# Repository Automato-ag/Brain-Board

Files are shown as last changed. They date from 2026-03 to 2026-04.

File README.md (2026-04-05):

# Brain Board — Automato Ag

Firmware and documentation for the **Automato Brain Board V2.0**, an ESP32-C6 based agricultural IoT node with onboard temperature, humidity, and light sensing, ESP-NOW mesh networking, relay control, and a self-hosted web dashboard served directly from the board.

---

## Hardware

| Component | Details |
|---|---|
| MCU | ESP32-C6-MINI-1-N4, 160 MHz, 4 MB Flash |
| Temp/Humidity | SHTC3 — I2C 0x70 (fixed) |
| Light | TSL2591 — I2C 0x29 (fixed) |
| I2C Bus | SDA = IO6, SCL = IO7 |
| Blue LED | IO23 |
| Red LED | IO22 |
| Boot Button | IO9 — see Boot Button section below |
| Qwiic/STEMMA QT | J2, J3 — GND / 3V3 / SDA / SCL |
| Logic Level | 3.3V only — GPIO pins not 5V tolerant |

See [`hardware/Brain_Board_Reference.md`](hardware/Brain_Board_Reference.md) for full pinout and hardware notes.

---

## Firmware

### Current Version

| Sketch | Version |
|---|---|
| [`BrainBoard_v110`](firmware/BrainBoard/BrainBoard_v110/) | **v1.1.0** |

All boards run the same unified firmware. There is no separate Host or Remote build — role (gateway, relay, isolated) is determined automatically at runtime based on WiFi connectivity.

### Required Libraries

Install all of the following via **Arduino Library Manager**:

- `Adafruit SHTC3 Library`
- `Adafruit TSL2591`
- `Adafruit BusIO` *(installed automatically as dependency)*
- `Adafruit Unified Sensor` *(installed automatically as dependency)*
- `SparkFun TCA9534` *(for Qwiic GPIO relay control)*

### Arduino IDE Settings

| Setting | Value |
|---|---|
| Board | ESP32C6 Dev Module |
| USB CDC On Boot | **Enabled** — required; board crashes on Serial without this |
| Partition Scheme | **Custom** — required; uses `partitions.csv` in sketch folder |
| Upload Speed | 921600 |

> **Note:** USB CDC on Boot must be re-enabled each Arduino IDE session — it does not always persist.

### First Flash

1. Open `BrainBoard_v110/BrainBoard_v110.ino` in Arduino IDE
2. Set board settings as above
3. **Sketch → Upload** — flash firmware
4. **Tools → ESP32 Sketch Data Upload** — upload `data/` folder to LittleFS
5. Open Serial Monitor at 115200 baud, press RESET
6. Connect phone or laptop to the `Automato-XXXX` WiFi network
7. Open `http://192.168.4.1/setup` — enter your Network Name, password, and WiFi credentials
8. Board joins your network and is accessible at `http://networkname.local`

### OTA Updates (after first flash)

- Navigate to `http://boardname.local/update` or `http://192.168.4.1/update`
- Upload new firmware `.bin` or new LittleFS filesystem image
- Firmware and webapp update independently — UI changes do not require reflashing firmware

### Boot Button (IO9)

| Action | Behavior |
|---|---|
| Hold 5s at **startup** | Clears all stored credentials and settings, then reboots |
| Short press during **runtime** | Opens a 10-minute SoftAP access window — board stays accessible at `192.168.4.1` even when on WiFi (useful for field configuration) |

---

## Dashboard

The Brain Board serves a complete webapp directly from its own flash memory — no internet, cloud, or external server required. Works in a field with no cell service.

### Tabs

| Tab | Description | Status |
|---|---|---|
| Dashboard | Live sensor readings, relay control, Agri Data sidebar | Live |
| Devices | Local + peer I2C scan, user-defined device labels, address reference | Live |
| Rules | Automation rule engine — local and cross-board conditions | v1.2 |
| Settings | Display & Behavior (units, refresh rate, auto-sync), Agri Data Sources, Board Settings | Live |
| Network | Mesh topology — board roles, peers, gateway address | Live |

### HTTP Endpoints

| Endpoint | Method | Description |
|---|---|---|
| `/` | GET | Dashboard webapp (served from LittleFS) |
| `/data` | GET | Sensor JSON + relay state + network info |
| `/peers` | GET | Peer list JSON |
| `/version` | GET | Firmware + webapp version, mDNS name, network name |
| `/relay` | GET | Relay control (`?state=0\|1`, `?override=auto`) |
| `/relay/status` | GET | Relay state JSON |
| `/i2c-scan` | GET | Local I2C bus scan |
| `/remote-scan` | POST/GET | Peer I2C scan via ESP-NOW |
| `/time` | POST | Set board time from browser |
| `/settings` | POST | Save board name / Network Name / password |
| `/proxy` | GET | HTTPS relay — board fetches external API on browser's behalf (`?url=`); allowlisted domains only |
| `/prefs` | GET | Read dashboard preferences from LittleFS (`/prefs.json`) |
| `/prefs` | POST | Write dashboard preferences JSON to LittleFS |
| `/setup` | GET/POST | WiFi provisioning form |
| `/wifi/reset` | POST | Clear WiFi credentials + reboot |
| `/update` | GET | OTA update UI |
| `/update/firmware` | POST | Flash new firmware `.bin` |
| `/update/filesystem` | POST | Flash new LittleFS image |

### Agri Data Sidebar

External API calls are routed through the board's `/proxy` endpoint so they work when connected to the board's SoftAP (phone in the field with no direct internet). All sources are free and require no API keys.

Data sources can be enabled or disabled individually from **Settings → Agri Data Sources**.

| Parameter Group | Source |
|---|---|
| Weather, Wind, Cloud Cover, Outdoor Humidity | Open-Meteo |
| Solar, UV Index, Shortwave Radiation | Open-Meteo |
| First Light, Sunrise, Solar Noon, Sunset, Day Length | Sunrise-Sunset.org |
| Soil Temperature and Moisture, ET₀, VPD | Open-Meteo |
| Frost Risk (derived) | Open-Meteo (radiative cooling model) |
| Growing Degree Days — season to date (derived) | Open-Meteo + ERA5 archive |
| Chill Hours — season to date (derived) | Open-Meteo + ERA5 archive |
| Photoperiod — day length classification (derived) | Sunrise-Sunset.org |
| Moon Phase, Moonrise, Moonset | USNO + Sunrise-Sunset.org |
| NWS Frost Alerts | NOAA National Weather Service |
| PM2.5, Pollen | Open-Meteo Air Quality |
| DLI Accumulator (onboard sensor) | TSL2591 lux — accumulated in firmware |

---

## ESP-NOW Mesh

All Brain Boards on the same Network Name automatically form a mesh using ESP-NOW. No configuration required beyond giving boards the same Network Name in `/setup`.

| Role | Condition | Behavior |
|---|---|---|
| Gateway | Board has active WiFi | Serves dashboard at `networkname.local`; syncs NTP time; relays peer sensor data |
| Relay | No WiFi, peer discovered | Seeks mesh channel, locks on discovery, forwards sensor data to gateway via ESP-NOW |
| Isolated | No WiFi, no peers found | Seeks continuously; accessible at `192.168.4.1` via its own SoftAP |

**Channel seek:** Non-WiFi boards cycle through channels 1–11 (US), restarting their SoftAP on each channel to keep the radio active for ESP-NOW reception. Lock occurs on first matching MSG_HELLO beacon.

**Plugin hooks:** Add a `custom.ino` file to the sketch folder to extend functionality without modifying core firmware. Available hooks: `customSetup()`, `customLoop()`, `customDataJSON()`.

---

## Relay Control

- GPIO expander: SparkFun Qwiic GPIO (TCA9534) at I2C address 0x27, connected via Qwiic cable
- Relay defaults **OFF** at all times — boot, sensor failure, I2C error, connectivity loss
- Manual ON/OFF toggle in dashboard always overrides automation
- Rule engine arriving in v1.2

## Relay Safety Contract

Relays default **OFF** under all failure conditions: boot, sensor failure, WiFi loss, cloud loss, browser closed, no rules configured, conflicting rules, hardware expander not found.

**There is no condition under which a relay defaults ON.**

---

## Roadmap

| Version | Feature | Status |
|---|---|---|
| v0.8.1 | Tab navigation shell, I2C Scanner tab, `/i2c-scan` endpoint | Complete |
| v0.9 | Devices tab, remote I2C scan via ESP-NOW, Network Name in `/setup` | Complete |
| v1.0 | Settings tab, Network tab stub, `POST /settings` endpoint | Complete |
| v1.1 | ESP-NOW mesh — unified firmware, MSG_HELLO beacon, dynamic gateway, `networkname.local`, 1-hop relay, live Network tab, plugin hooks | Complete |
| v1.2 | Rules tab — firmware rule engine, LittleFS persistence, local + peer conditions, recipe database | Next |
| v1.3 | Multi-hop relay, routing tables, cross-board rules | Planned |

---

## Repository Structure

```
Brain-Board/
├── README.md
├── CHANGELOG.md
├── LICENSE
├── .gitignore
├── firmware/
│   ├── BrainBoard/
│   │   └── BrainBoard_v110/            <- current (v1.1)
│   │       ├── BrainBoard_v110.ino
│   │       ├── partitions.csv
│   │       └── data/
│   │           ├── index.html
│   │           └── version.txt
│   ├── BrainBoard_Host/                <- legacy (pre-v1.1)
│   └── BrainBoard_Remote/              <- legacy (pre-v1.1, retired)
├── docs/
│   ├── Roadmap.md
│   ├── QuickStart.md
│   ├── RelayControl.md
│   ├── AgriDataSidebar.md
│   ├── ESP32C6_Capabilities.md
│   ├── I2C_Address_Map.md
│   └── ProductFamily.md
├── hardware/
│   ├── README.md
│   ├── Brain_Board_Reference.md
│   └── kicad/
│       └── Brain_Board_V2.0/
└── tools/
    └── I2C_Scanner/
        └── I2C_Scanner.ino
```

---

## License

MIT License — see [LICENSE](LICENSE) for details.

---

*Automato Ag — [automato.ag](https://automato.ag)*

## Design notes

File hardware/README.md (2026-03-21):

# Automato Brain Board V2.0 — Hardware Files

This folder contains hardware design files for the Automato Brain Board V2.0.

---

## Files

### Brain_Board_Reference.md
Complete hardware reference — MCU specs, pin definitions, I2C addresses, power rails, and peripheral wiring.

### kicad/Brain_Board_V2.0/
KiCad 9.0 design files for the Brain Board V2.0 PCB.

| File | Description |
|---|---|
| `Automato_V2.0.kicad_sch` | Schematic |
| `Automato_V2.0.kicad_pcb` | PCB layout |
| `Automato_V2.0.kicad_pro` | KiCad project file |

**To open:** Install [KiCad 9.0](https://www.kicad.org/download/) and open `Automato_V2.0.kicad_pro`.

---

## Key Specs

| Property | Value |
|---|---|
| MCU | ESP32-C6-MINI-1-N4 |
| Flash | 4 MB |
| Onboard sensors | SHTC3 (temp/humidity, 0x70), TSL2591 (light, 0x29) |
| I2C | SDA = IO6, SCL = IO7 |
| Connector | 2× Qwiic (JST-PH 4-pin, 3.3V) |
| Power | USB-C, 3.3V logic |
| Logic level | 3.3V — GPIO pins not 5V tolerant |

---

## Onboard I2C Addresses (fixed — cannot be changed)

| Address | Device | Function |
|---|---|---|
| 0x29 | TSL2591 | Ambient light |
| 0x70 | SHTC3 | Temperature + humidity |

### Reserved addresses (next revision)
| Address | Device | Notes |
|---|---|---|
| 0x68 | DS3231 RTC | Onboard RTC planned for next Brain Board revision |

---

## Architecture Note

The Brain Board is always a discrete, standalone PCB. It is never integrated into a peripheral board. All output capability (relay, MOSFET, GPIO expansion) lives on separate peripheral boards connected via cable.

See [`docs/Roadmap.md`](../docs/Roadmap.md) for full hardware roadmap including the 6-pin Automato connector specification and planned peripheral board lineup.

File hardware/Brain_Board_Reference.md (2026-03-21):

# Automato Brain Board V2.0 — Hardware Reference

## MCU

| Property | Value |
|---|---|
| Chip | ESP32-C6-MINI-1-N4 |
| Architecture | RISC-V dual core (HP core 160 MHz + LP core 20 MHz) |
| Clock | 160 MHz |
| Flash | 4 MB |
| RAM | 512 KB |
| WiFi | 802.11 b/g/n/ax (2.4 GHz) + ESP-NOW LR |
| Bluetooth | BLE 5.0 |
| Logic Level | 3.3V — GPIO pins NOT 5V tolerant |

> The HP core runs all Arduino firmware. The LP core is a secondary low-power processor that can operate independently while the HP core sleeps — see [ESP32-C6 Unexplored Capabilities](../docs/ESP32C6_Capabilities.md).

---

## I2C Bus

| Pin | GPIO |
|---|---|
| SDA | IO6 |
| SCL | IO7 |

### Onboard I2C Devices

| Device | Address | Function |
|---|---|---|
| SHTC3 | 0x70 | Temperature + Relative Humidity |
| TSL2591 | 0x29 | Ambient Light (lux, visible, infrared) |

### Qwiic / STEMMA QT Connectors

- **J2** and **J3** — both connected to the same I2C bus
- Pinout: GND · 3V3 · SDA · SCL
- Compatible with all SparkFun Qwiic and Adafruit STEMMA QT devices
- **Note:** Power only (3.3V) — no 5V available on Qwiic connectors

---

## GPIO

| Pin | Function | Notes |
|---|---|---|
| IO6 | SDA | I2C data |
| IO7 | SCL | I2C clock |
| IO9 | Boot button | Active LOW, pulled up |
| IO22 | Red LED | Active HIGH |
| IO23 | Blue LED (LED_BUILTIN) | Active HIGH |
| EN | Reset button (SW1) | Hardware reset |

---

## Power

| Rail | Details |
|---|---|
| Input | USB-C |
| Operating voltage | 3.3V |
| GPIO output | 3.3V max |

---

## Relay Expansion (Qwiic GPIO)

For relay control, connect a **SparkFun Qwiic GPIO (TCA9534)** to J2 or J3.

| Property | Value |
|---|---|
| I2C address | 0x27 (all address jumpers bridged — SparkFun Qwiic GPIO default) |
| Library | SparkFun TCA9534 (Arduino Library Manager) |
| Relay board | Amazon B0CHFJSNP6 (5V coil, optoisolated, active HIGH) |
| Signal level | 3.3V from TCA9534 is sufficient to trigger optocoupler |
| Relay power | 5V from USB hub (independent of Brain Board) |

### Wiring

```
Brain Board Qwiic (J2 or J3)
  └── SparkFun Qwiic GPIO (TCA9534, 0x27)
        └── Pin 0 → Relay Board IN
```

### Power Setup

```
USB-C Hub
  ├── Port A → Brain Board USB-C (3.3V logic power)
  └── Port B → Relay Board USB-C (5V coil power)
               Shared ground via hub — no ground loop
```

---

## Notes

- No LoRa radio on Brain Board V2.0
- No LCD or display
- No SD card
- ESP-NOW Long Range (LR) mode requires enabling on AP interface **after** WiFi connects — not before

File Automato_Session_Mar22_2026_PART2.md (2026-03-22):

# Automato Session — March 22, 2026 (Part 2)

## Session Overview

This session began by committing the remaining v0.9 changes from Part 1, then pivoted into a deep architectural research and planning session covering mesh networking options, board mobility, multi-hop relay design, and a full roadmap revision. No new firmware or webapp code was written — this was a strategy and architecture session.

---

## Commits Made

**Commit:** `v0.9: Automato Network Name, WiFi reset UX, Network Name in Dashboard`
- `/setup` form: Network Name + Network Password fields, NVS storage (netname, netpass)
- Auto-generated default name (`automato-XXXX`) from MAC suffix if NVS empty
- `/version` JSON: added `networkName` field
- WiFi reset flow: shows step-by-step reconnection instructions with `http://192.168.4.1/setup`
- Setup banner href changed from `/setup` to `http://192.168.4.1/setup`
- Dashboard WiFi status: displays Network Name below mDNS line

**User preference established:** Never include `Co-Authored-By: Claude Sonnet 4.6 <noreply@anthropic.com>` in commit messages. Saved to feedback memory.

---

## Research: Mesh Networking Options for ESP32-C6

A full comparative analysis was done before deciding on the v1.1 mesh approach. Results:

| Option | Verdict | Reason |
|---|---|---|
| ESP-Mesh-Lite | ❌ | ESP-IDF 5.x only — no Arduino. Patches ESP-IDF at build time. Can't link from Arduino sketch without patched board package. |
| painlessMesh | ❌ | Requires arduino-esp32 v2.0.x; ESP32-C6 requires v3.x. Mutually exclusive. |
| zh_network | ❌ | ESP32-C6 unverified; tested on PlatformIO only, not Arduino IDE. 218-byte max payload. |
| Thread / OpenThread | ⏳ | ESP32-C6 hardware supports 802.15.4 natively. But requires ESP-IDF, needs Border Router. Deferred to v2.0+. |
| Custom ESP-NOW | ✅ | Arduino-native, verified on ESP32-C6, no external dependencies, stable indefinitely. |

### Could ESP-Mesh-Lite live in a separate layer?

The architectural concept is sound — pre-compile ESP-Mesh-Lite as a library layer, expose a clean API to Arduino sketches. Theoretically achievable via Path A: apply ESP-Mesh-Lite patches to the ESP-IDF build inside the `automato-arduino` custom board package.

**Why not now:** Each upstream release of arduino-esp32 or ESP-Mesh-Lite requires a full ESP-IDF rebuild (~2–4 hours CI), patch conflict resolution, and hardware smoke test. For a small team this is unsustainable. Revisit when bandwidth exists.

### The "never needs an update" principle

External mesh libraries introduce permanent update dependencies. The most robust firmware owns everything it depends on. Custom ESP-NOW code, once written, is stable indefinitely regardless of what Espressif ships.

---

## Key Architectural Decisions

### Board Mobility Is the Core Use Case

Boards are NOT fixed-installation devices. They move with:
- Plants transplanted from germination to garden bed
- Pots relocated indoors/outdoors seasonally
- Garden beds rearranged between harvests

**Fixed Host/Remote roles are the wrong model.** They require manual reconfiguration every time a board moves. This is unacceptable.

### Every Board Is a Full Peer

All Brain Boards are identical hardware running identical firmware. Every board already has: web server, LittleFS webapp, REST API, NVS rules, sensors, relay control. The "gateway" role is a runtime state, not a hardware assignment.

### ESP-NOW Peer Limits

- Hard limit: **20 peers per board** (`ESP_NOW_MAX_TOTAL_PEER_NUM`) — not configurable
- Star topology max: 1 gateway + 20 direct peers = 21 boards
- With 1 relay tier: ~50–80 boards
- With 2 relay tiers: ~150–200 boards
- Covers all realistic Automato installations

### Multi-Hop Relay — Verified Viable

Scenario confirmed: Board4 moves from Board2's range to Board3's range. Sequence:
1. Board4's MSG_HELLO beacon received by Board3 (new neighbor)
2. Board3 registers Board4 as ESP-NOW peer
3. Board3 propagates routing update to Board1 (gateway)
4. Board1 updates routing table: Board4 reachable via Board3
5. Transition time: 1–3 beacon cycles

**Duplicate-drop mechanism:** Each packet carries `originMac + seq`. Any board that has already forwarded a given combination drops it — prevents routing loops.

**TTL guard:** Packets carry a TTL (default 5). Decrements each hop. Dropped at 0 regardless. Second line of defense against loops.

**Bidirectional:** Sensor data flows toward gateway. Commands (relay toggle, config changes) flow back via the same path in reverse.

---

## Revised Roadmap

| Version | Scope |
|---|---|
| v0.9 | ✅ Complete |
| v1.0 | Rules tab + Settings tab + Network tab (stub) + plugin hooks + recipe database |
| v1.1 | Auto-discovery (MSG_HELLO) + dynamic gateway + `networkname.local` + 1-hop relay + unified firmware |
| v1.2 | Multi-hop relay + routing tables + full peer equality |

### v1.1 Architecture Detail

**MSG_HELLO beacon:**
```cpp
typedef struct {
  uint8_t  type;            // MSG_HELLO (0x03)
  char     networkName[33]; // must match to join
  char     boardName[33];   // individual board identity
  uint8_t  mac[6];          // sender MAC
  bool     hasWiFi;         // does this board have router connectivity?
} HelloPayload;
```
Any board receiving a MSG_HELLO with matching Network Name registers the sender as an ESP-NOW peer automatically. No manual configuration.

**Dynamic gateway election:** Board with active WiFi router connectivity = gateway. If multiple boards have WiFi, highest RSSI wins. Changes automatically. No user action.

**`networkname.local` mDNS:** Gateway advertises Network Name as mDNS hostname. User's bookmark (e.g., `southknox.local`) works regardless of which physical board is currently the gateway. Re-resolves within ~60 seconds of a gateway change.

**Graceful degradation:**
| State | Behavior |
|---|---|
| On WiFi | Reachable at `boardname.local`, visible in network dashboard |
| ESP-NOW only (1 hop) | Data relayed through nearest peer, visible in dashboard |
| Completely isolated | Tier 3 rules run; rejoins automatically when back in range |

**Unified firmware:** `BrainBoard_Host` and `BrainBoard_Remote` merge into a single `BrainBoard` firmware. Do not invest in extending `BrainBoard_Remote` — it will be absorbed in v1.1.

### v1.2 Architecture Detail

**Packet structure:**
```cpp
typedef struct {
  uint8_t  type;
  uint8_t  originMac[6];  // for duplicate-drop
  uint16_t seq;           // per-board sequence number
  uint8_t  ttl;           // decrements per hop; drop at 0
  uint8_t  payload[];
} MeshPacket;
```

Routing tables per board, updated within 1–3 beacon cycles when topology changes.

---

## v1.0 Decisions Confirmed

**Rules tab:**
- Local board sensors only in v1.0
- Cross-board sensor references require mesh peer identity (v1.2)
- Rule engine structs already written in firmware — `evaluateRules()` commented out of `loop()`, ready to activate

**Settings tab contents (v1.0):**
- Board name (individual identity)
- Network Name + password (mirrors `/setup` — editable without knowing the `/setup` URL)
- WiFi credentials reset
- Start with these; expand as capabilities grow

**Network tab:**
- Stub in v1.0 — shows single-board connectivity status and current role
- Visual peer map (all boards, roles, relay paths) in v1.1

**Role indicator:**
- Visible on every board's dashboard
- v1.0: Host / Remote (fixed roles still in use)
- v1.1+: Gateway / Relay / Isolated (dynamic)

---

## Files Updated This Session

- `docs/Roadmap.md` — full rewrite of Multi-Board Networking section; version table updated; Known Decisions expanded with 7 new entries; ESP-Mesh-Lite references removed
- `CLAUDE.md` — v0.9 marked complete; 5-tab structure documented; v1.0/v1.1 scope updated; firmware naming warning added; two new guiding principles added
- `memory/project_architecture.md` — roadmap updated, ESP-NOW/Networking section rewritten with new mesh architecture
- `memory/feedback_working_style.md` — no Co-Authored-By in commits

---

## Open Questions Carried Forward

1. Connector decision — two 6-pin Automato ports, or one 6-pin + one Qwiic?
2. Thread/OpenThread — revisit at v2.0 when ESP-IDF path is clearer
3. Multi-board webapp design — discuss before v1.1 (gateway aggregates all peer dashboards)
4. Cross-board rules UI — how does user specify "Board2 soil moisture" vs "Board1 soil moisture"? Deferred to v1.2 design phase.
5. Historical data logging — SD card firmware + browser File System API — which version?

---

## Next Steps

Build v1.0. Starting options:
- **Rules tab** — firmware: `/rules` GET/POST endpoints, NVS persistence, activate `evaluateRules()` in loop; webapp: rule builder UI
- **Settings tab** — webapp only (LittleFS deploy, no firmware reflash): board name, Network Name, WiFi reset form
- **Network tab stub** — webapp only: connectivity status, role display

Session ended before v1.0 work began.

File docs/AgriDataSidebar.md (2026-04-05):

# Agri Data Sidebar

## Overview

The Agri Data sidebar provides real-time external environmental data alongside the onboard sensor readings. All API calls are routed through the board's `/proxy` endpoint — this ensures data loads correctly when accessing the board via its SoftAP in the field (no direct internet from the browser required). All sources are free; no API keys are required.

---

## Location

Enter any of the following in the location field:

- City name: `Winnipeg`
- City + country: `Saskatoon, CA`
- ZIP/postal code: `R3C 0V8`
- Latitude, Longitude: `49.8954, -97.1385`

Location is resolved via the **Open-Meteo Geocoding API** and persisted to the board's `/prefs` endpoint. External data refreshes every **60 seconds** after a location is set.

---

## Available Parameters

### Weather & Forecast
*Source: [Open-Meteo](https://open-meteo.com)*

| Parameter | Unit (Metric) | Unit (Imperial) |
|---|---|---|
| Outdoor Temperature | °C | °F |
| Precipitation | mm | in |
| Wind Speed | km/h | mph |
| Wind Direction | Cardinal + degrees | Cardinal + degrees |
| Cloud Cover | % | % |
| Outdoor Humidity | % | % |

### Solar & Light
*Source: Open-Meteo + [Sunrise-Sunset.org](https://sunrise-sunset.org/api)*

| Parameter | Notes |
|---|---|
| First Light / Civil Dawn | Start of civil twilight — earliest usable light |
| Sunrise | |
| Solar Noon | Peak sun angle |
| Sunset | |
| Last Light / Civil Dusk | End of civil twilight |
| Day Length | Hours and minutes |
| UV Index | |
| Shortwave Radiation | W/m² |
| Photoperiod | Day length classification (Short / Neutral / Long) + seasonal trend |

### Soil & Agriculture
*Source: Open-Meteo*

| Parameter | Unit (Metric) | Unit (Imperial) |
|---|---|---|
| Soil Temperature (0–7 cm) | °C | °F |
| Soil Temperature (7–28 cm) | °C | °F |
| Soil Moisture | m³/m³ | m³/m³ |
| Evapotranspiration (ET₀) | mm | in |
| Vapor Pressure Deficit (VPD) | kPa | kPa |
| Frost Risk (derived) | Low / Moderate / High / Severe — radiative cooling model from outdoor temp, cloud cover, wind speed | |
| Growing Degree Days | °C·day or °F·day — season-to-date accumulation since Jan 1 (base 10°C / 50°F) | |
| Chill Hours | hrs — season-to-date accumulation since Nov 1 (N) / May 1 (S), at or below 7.2°C (45°F); ±5% estimate | |

### Moon
*Source: USNO + Sunrise-Sunset.org*

| Parameter | Notes |
|---|---|
| Moon Phase | New / Waxing Crescent / First Quarter / Waxing Gibbous / Full / Waning Gibbous / Last Quarter / Waning Crescent |
| Moonrise | |
| Moonset | |

### Weather Alerts
*Source: [NOAA National Weather Service](https://api.weather.gov)*

| Parameter | Notes |
|---|---|
| NWS Frost Alerts | Active frost / freeze warnings and advisories for the selected location |

### Air Quality
*Source: [Open-Meteo Air Quality API](https://air-quality-api.open-meteo.com)*

| Parameter | Unit |
|---|---|
| PM2.5 Particulates | μg/m³ |
| Pollen Count | Low / Moderate / High / Very High |

### DLI Accumulator (onboard sensor)
*Source: TSL2591 lux sensor — accumulated in firmware*

| Parameter | Notes |
|---|---|
| Daily Light Integral | mol/m² — accumulated photosynthetically active light since midnight. Resets at midnight. Set a crop target in Settings → Board Settings to track progress as a percentage. |

---

## External APIs Used

All free, no authentication required, no API keys. All requests routed through the board's `/proxy` endpoint.

| API | Domain | Used For |
|---|---|---|
| Open-Meteo Geocoding | `geocoding-api.open-meteo.com` | Location search |
| Open-Meteo Forecast | `api.open-meteo.com` | Weather, soil, solar, UV, ET₀, VPD, frost risk, GDD bridge |
| Open-Meteo ERA5 Archive | `archive-api.open-meteo.com` | Season-to-date GDD and Chill Hours accumulation |
| Sunrise-Sunset.org | `api.sunrise-sunset.org` | Sun/moon times, day length, moon phase, photoperiod |
| USNO | `aa.usno.navy.mil` | Moon phase confirmation |
| Open-Meteo AQI | `air-quality-api.open-meteo.com` | PM2.5, pollen |
| NOAA NWS | `api.weather.gov` | Frost/freeze alerts |

---

## Units Toggle

Switch between **Metric** and **Imperial** at any time using the toggle in **Settings → Display & Behavior**. The change applies immediately to all active parameter chips and to the board sensor readings. Unit preference is persisted to the board.

---

## Preferences Persistence

Location, active parameters, units, and source enable/disable state are all persisted to the board's `/prefs` endpoint (LittleFS + NVS backup). Settings survive browser/device changes and LittleFS firmware uploads.

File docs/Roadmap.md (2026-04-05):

# Automato Brain Board — Product Roadmap

Last updated: 2026-03-23

This document captures the planned development path for the Automato Brain Board
firmware, dashboard, and automato.ag platform integration. It is a living document
— updated as decisions are made and architecture evolves.

---

## Guiding Principles

- **Offline first** — the board must function without internet or even a browser open
- **Progressive enhancement** — each tier adds capability without breaking the tier below
- **No lock-in** — users have full access to their sketch code at all times
- **Safe by default** — outputs default to their hardware-defined failsafe state under any failure
- **Useful out of the box** — a new Brain Board should be immediately functional
  with no configuration, no internet, and no external tools required
- **Non-proprietary** — third-party I2C devices and hardware are first-class citizens;
  Automato hardware integrates into other ecosystems and vice versa
- **Novice-accessible** — most users are not programmers; every feature must be
  reachable without writing code; intermediate users should be able to extend
  without forking

---

## The Stem Cell Concept

The Brain Board ships with Base Firmware — a stable, minimal foundation
analogous to stem cells in biology. Like stem cells, it is undifferentiated: it
contains the basic machinery of life and the ability to become anything, but has
not yet specialised into a specific function.

From this base, the user (or automato.ag) delivers specialised firmware via OTA —
irrigation control, environmental monitoring, relay automation, etc. — without
ever needing a USB cable or the Arduino IDE again.

The base firmware is:
- Stable — versioned separately, rarely changes
- Trusted — the known-good fallback if a feature firmware update fails
- Self-sufficient — hosts a complete webapp locally, works with no internet
- Aware — scans I2C on boot, knows what hardware is connected

---

## UX Architecture

Three additive layers — each lower layer always works regardless of upper layer availability:

| Layer | Access | Features |
|---|---|---|
| `index.html` (offline) | Local network only | All core features — sensor readings, relay control, rules, settings |
| `index.html` (online) | Local network + internet | Core features + internet-dependent features (Agri Data, weather) |
| automato.ag | Any network | Extended UX too large for the board + remote viewing |

**All user data lives on the board.** automato.ag holds only an ephemeral relay cache —
no user accounts, no stored preferences, no email, no registration required.

---

## Cloud Identity

- Automato Network Name and password are set during `/setup`
- Cloud token = `hash(Automato Network Name + password)` — derived locally on the board
- Network Name alone → mesh membership (boards find each other)
- Network Name + Password → cloud identity (board authenticates to automato.ag relay)
- automato.ag never sees credentials — only the derived token
- Auto-generated default name (e.g. `automato-garden-7e20`) makes collision negligible without hardware salt

---

## Base Firmware

### What Ships on Every Brain Board

```
Base Firmware
├── WiFi provisioning (AP mode on first boot, STA mode after setup)
├── OTA update receiver (/update endpoint)
├── Basic sensor reading (SHTC3, TSL2591)
├── I2C scan on boot — detects connected devices
├── Offline webapp (served from LittleFS)
└── NVS storage for WiFi credentials and device settings
```

### First Boot Experience (no internet required)

1. User powers Brain Board for the first time
2. Board creates its own WiFi access point: Automato-XXXX
3. User connects phone or laptop to Automato-XXXX
4. Opens http://192.168.4.1 in browser
5. Full Automato webapp loads directly from the board
6. User sees live sensor readings immediately
7. User enters their WiFi credentials and optionally sets Automato Network Name + password
8. Board joins their network, accessible at http://brainboard.local
9. If internet available — board registers with automato.ag via derived cloud token

### After First Boot

- Board always accessible at http://brainboard.local on local network
- Offline webapp always available regardless of internet connectivity
- automato.ag enhances the experience when internet is available
- OTA updates can be pushed from automato.ag or uploaded manually

---

## Flash Memory Layout (4MB)

```
4MB Flash
├── Base firmware code         ~500KB
├── OTA partition (copy)       ~500KB   (required for safe OTA)
├── LittleFS (webapp + files)  ~2MB     (webapp HTML/CSS/JS lives here)
└── NVS (settings, rules)      ~256KB
```

---

## Firmware Version Roadmap

| Version | Scope | Status |
|---|---|---|
| v0.8.1 | Tab nav shell, I2C Scanner tab, `/i2c-scan` endpoint | ✅ complete |
| v0.9 | Devices tab + remote I2C scan via ESP-NOW + Automato Network Name | ✅ complete |
| v1.0 | Settings tab (functional) + Network tab (stub) + `POST /settings` endpoint | ✅ complete |
| v1.1 | ESP-NOW mesh: MSG_HELLO beacon, unified firmware, dynamic gateway, `networkname.local`, 1-hop relay, live Network tab peer map + plugin hooks | ✅ complete |
| v1.2 | Rules tab: firmware rule engine, LittleFS rule storage, local + peer sensor conditions, relay actions + recipe database | post-v1.1 |
| v1.3 | Multi-hop relay + routing tables + full peer equality + cross-board rule conditions | post-v1.2 |

### v0.9 Scope — Complete ✅

**Devices tab (replaces I2C Scanner tab):**
- Host I2C scan via `/i2c-scan` endpoint
- Remote board I2C scan via ESP-NOW (`MSG_SCAN_REQUEST` / `MSG_SCAN_RESPONSE`)
- User device definition form — name and description stored in localStorage by address
- Collapsible I2C address map (full 0x08–0x77 grid)
- 5 tabs present: Dashboard · Devices · Rules · Settings · Network

**`/setup` additions:**
- Automato Network Name field — auto-generated default (`automato-XXXX`), user-editable
- Password field — stored in NVS
- Network Name exposed in `/version` JSON as `networkName`
- Network Name displayed in Dashboard WiFi status area

**WiFi reset UX:**
- Reset flow shows step-by-step reconnection instructions with AP SSID and `http://192.168.4.1/setup` link

### v1.0 Scope — Complete ✅

- Settings tab: board name, Network Name + password, WiFi reset — pre-fills from `/version` on open
- Network tab (stub): HOST/REMOTE role badge, board name, mDNS address, Network Name, WiFi status; "Coming in v1.1" section explains auto-discovery
- `POST /settings` endpoint: saves board name, Network Name, and password to NVS without requiring WiFi credentials (unlike `POST /setup` which requires `ssid`)
- Stable 5-tab layout established: Dashboard · Devices · Rules · Settings · Network

### v1.1 Scope — Complete ✅

Two-board hardware test confirmed 2026-03-28.

- **Unified firmware:** `BrainBoard_Host` and `BrainBoard_Remote` merged into single `BrainBoard` firmware — all boards are full peers
- **MSG_HELLO beacon:** boards broadcast Network Name + board name + MAC + hasWiFi on startup and periodically; matching boards auto-register as ESP-NOW peers
- **Dynamic gateway election:** board with active WiFi router connection = gateway; changes automatically when boards move; strongest RSSI wins if multiple candidates
- **`networkname.local` mDNS:** gateway advertises Network Name as mDNS hostname (e.g., `southknox.local`); user bookmark works regardless of which board is gateway
- **1-hop relay:** boards out of WiFi range relay sensor data through nearest ESP-NOW peer
- **Network tab (live):** peer map showing all discovered boards, their roles, relay paths, and WiFi status
- **Plugin hook architecture:** `customSetup()`, `customLoop()`, `customDataJSON()` weak functions in base firmware; user adds `custom.ino` to sketch folder
- **SoftAP captive portal:** `onNotFound` redirects to `/` (dashboard) when provisioned, `/setup` when not — primary phone access method for field use
- **`/proxy` endpoint:** board-side HTTPS relay for external API calls; allowlisted domains only; enables agri data on SoftAP without direct browser internet access
- **`/prefs` endpoint:** LittleFS-backed preference persistence with NVS backup (survives LittleFS uploads); stores location, active params, units, refresh rate, card visibility, DLI settings, font scale, and more
- **Agri Data sidebar phases 1–5b:** weather, solar, moon, soil, AQI, NWS alerts, frost risk, photoperiod, growing degree days (season-to-date), chill hours (season-to-date, asymmetric linear model)

### v1.1 Shippability Checklist

- [x] Unified firmware — single `BrainBoard.ino` replaces both Host and Remote
- [x] MSG_HELLO beacon implemented and tested (2+ boards auto-discover)
- [x] Dynamic gateway election tested (gateway transfers when board moves)
- [x] `networkname.local` mDNS verified from gateway board
- [x] 1-hop relay verified (board out of WiFi range, data reaches dashboard)
- [x] Network tab: live peer map populated from beacon data
- [x] Plugin hook architecture implemented and documented

### v1.2 Scope

- Rules tab: full firmware rule engine, LittleFS rule storage, `/rules` GET/POST endpoints
- Rule conditions: local board sensors (temp, humidity, light); peer board sensors (using peer MAC identity established in v1.1)
- Rule actions: local relay (TCA9534); future output boards (AC-01, DC-01–04) as they ship
- Rule schema designed for forward compatibility — `"source": "local"` in v1.2 becomes `"source": "peer:<mac>"` without migration
- Curated recipe database: 20–30 most common DIY sensors pre-defined in webapp (used for device naming in Devices tab and referenced in Rules conditions)
- Stable documented REST API — no breaking changes after v1.2

### v1.3 Scope

- Multi-hop relay + routing tables (see Multi-Board Networking section below)
- Cross-board rule conditions referencing boards 2+ hops away
- Full peer equality — no architectural distinction between any boards

---

## Plugin Hook Architecture (v1.1)

Intermediate users can add any Arduino library and custom sensor support without
touching the base firmware. Arduino concatenates all `.ino` files in a sketch folder
at compile time.

Base firmware defines weak hook functions — user implements them in `custom.ino`:

```cpp
// In BrainBoard_Host.ino — user never modifies this file
void __attribute__((weak)) customSetup() {}
void __attribute__((weak)) customLoop() {}
String __attribute__((weak)) customDataJSON() { return "{}"; }
```

`customDataJSON()` return value is merged into the `/data` response — custom sensor
values appear in the dashboard and are available to the rule engine automatically.

When base firmware updates: user replaces `BrainBoard_Host.ino` only. `custom.ino` is untouched.

Phase 2 cloud compile generates `custom.ino` from library templates — same architecture,
no friction for novice users.

---

## Unrecognized I2C Device Usability

| Level | User | Mechanism | Available |
|---|---|---|---|
| 0 | Novice | Built-in recipe database — one-click apply | v1.2 |
| 1 | Novice | Community recipe database — search and apply | Phase 3 |
| 2 | Intermediate | `custom.ino` plugin hook + Arduino library | v1.1 |
| 3 | Advanced | Full firmware fork | Always |

Novices with devices not in any database cannot use them until Level 0 or 1 coverage
exists. Document this clearly in user-facing materials.

---

## Platform Roadmap (automato.ag)

### Phase 0 — automato.ag/agridata Public Page

Goal: Standalone public agricultural data service — no Brain Board required, no accounts.

Features:
- All Agri Data sidebar datasets (weather, solar, moon, soil, AQI, alerts) + additional sources
- Interactive data graphs and charts
- Visual map viewer: zoom/pan, project API data as overlays
- Map layers: topographic, watershed, soil classification, and other relevant agricultural layers
- Available to anyone as a free public service

Why Phase 0: Builds brand awareness and demonstrates Automato's agricultural focus before a Brain Board is in hand. Entirely independent of Brain Board development — can be built in parallel.

### Phase 1 — Cloud Relay (Remote Viewing)

Goal: User can view their board's sensor data from any network, without user accounts.

Components:
- Board pushes sensor readings to automato.ag on interval (HTTP POST)
- Server stores latest readings in ephemeral relay cache keyed by cloud token
- automato.ag dashboard fetches and displays readings for the matching token
- NAT traversal: board maintains persistent outbound WebSocket — enables
  automato.ag to send commands (relay control, settings) back to the board
- No user accounts, no email, no registration

User flow:
1. User sets Automato Network Name + password in `/setup`
2. Board derives cloud token locally and registers with automato.ag
3. User visits automato.ag, enters Network Name + password
4. automato.ag derives same token, fetches their board's data
5. Dashboard shows live readings from any network, any device

### Phase 2 — Cloud Compile

Goal: User never needs Arduino IDE after first flash.

Components:
- Arduino CLI hosted on automato.ag server
- Automato board package installed on server
- Monaco Editor (VS Code engine) embedded in automato.ag
- Pre-made `.ino` template library (relay control, soil monitoring, etc.)
- Compile API: accepts `.ino` + `custom.ino`, returns compiled `.bin`
- Browser acts as relay: downloads `.bin` from automato.ag, pushes to board
  on local network via `/update` endpoint

Limitation: Browser must be open on the same local network as the board for OTA.

### Phase 3 — Community Device Recipe Database

Goal: Novice users can use any device another community member has already defined.

Components:
- Public device recipe search on automato.ag
- Community submission flow — no account required (GitHub PR model or anonymous submit)
- Recipes are public domain, attributed but not locked to a user
- Automato curates and validates submissions

---

## Three-Tier Automation Architecture

```
Tier 1 — Cloud (automato.ag)
  Full rule evaluation on server
  All data sources available (sensor data + Agri Data + weather)
  24/7, no browser required
  Requires internet + automato.ag uptime
    |
    v failover if cloud unreachable
Tier 2 — Browser
  Rule engine runs in dashboard tab
  Local network only
  No internet required
  Only active while browser is open
    |
    v failover if browser closed
Tier 3 — On-board (offline)
  Simplified rules in NVS flash
  Local sensor data only
  No network required
  Always running as safety net
  Relay defaults to failsafe state if no rules match
```

Failover: Tiers activate downward automatically on loss of higher tier.
Recovery: Board resumes highest available tier when connectivity restored.
Heartbeat: Configurable timeout — if no signal from higher tier within X seconds, Tier 3 takes over.

---

## Rule Engine Design (all tiers)

- Each rule has: name, priority (1=highest), logic operator, target relay(s), conditions
- Conditions compare sensor values: above / below / equals threshold
- Logic operators between conditions: AND, OR, NOT, XOR
- Conflict resolution: highest priority rule wins
- If no rules fire: relay defaults to hardware-defined failsafe state
- Manual dashboard toggle always overrides all rules regardless of priority
- Multiple rules can target the same relay — priority resolves conflicts

---

## Relay Safety Contract

Outputs default to the **hardware-defined failsafe state** under all failure conditions.
This includes: boot, sensor failure, WiFi loss, cloud loss, browser closed,
no rules configured, conflicting rules, and hardware expander not found.

**Failsafe state is hardware-selectable per output board** (next PCB revision and all
future output boards): a physical jumper selects Normally ON or Normally OFF.
A GPIO sense pin reads the jumper position at boot. The dashboard displays the
active failsafe mode prominently — amber warning if Normally ON.

Current Brain Board V2.0: failsafe = Normally OFF (hardcoded, no jumper on current hardware).

Rationale: Agricultural failure modes are asymmetric. A heater should default ON
(frost protection). A flood pump should default OFF. The installer, not the firmware,
makes this decision.

---

## Multi-Board Networking

### Design Principle: Boards Are Mobile

Brain Boards follow plants, seasons, and growing conditions. A board monitoring
germinating seedlings moves outside when transplanted. A board in a pot moves
with the pot. A board is repositioned between garden beds each season.

The architecture must accommodate this. Fixed Host/Remote roles require manual
reconfiguration every time a board moves. That is unacceptable.

**Every Brain Board is a full peer.** All boards run identical firmware with identical
capabilities: web server, webapp, REST API, NVS rules, sensors, relay control.
The "gateway" role (the board with active router connectivity that serves the
network dashboard) is determined dynamically — not assigned by the user.

### Current State (v0.9) — Fixed Roles, Manual Configuration

```
Router <─WiFi─> Board 1 (Host) <─ESP-NOW─> Board 2 (Remote)
                               <─ESP-NOW─> Board 3 (Remote)
```

Boards within ESP-NOW range of Board 1 only. Fixed roles. Remote MAC addresses
must be known in advance. Board 1 must remain closest to router.

### v1.1 Target — Auto-Discovery + Dynamic Gateway + 1-Hop Relay (next)

```
Router <─WiFi─> Gateway <─ESP-NOW─> Board 2
                        <─ESP-NOW─> Board 3
                        <─ESP-NOW─> Board 4 (out of WiFi range, relayed)
```

**Network Name beacon (MSG_HELLO):**
Every board broadcasts a small beacon packet on startup and periodically:
```cpp
typedef struct {
  uint8_t  type;            // MSG_HELLO
  char     networkName[33]; // must match to join
  char     boardName[33];   // individual board identity
  uint8_t  mac[6];          // sender MAC
  bool     hasWiFi;         // does this board have router connectivity?
} HelloPayload;
```
Any board that receives a `MSG_HELLO` with a matching Network Name registers
the sender as an ESP-NOW peer automatically. No manual MAC entry. No roles to assign.

**Dynamic gateway election:**
Whichever board has active WiFi router connectivity becomes the gateway.
If multiple boards have WiFi, the one with the strongest RSSI wins.
If the current gateway loses WiFi, another connected board takes over within
one beacon cycle. No user action required.

**`networkname.local` mDNS:**
The gateway advertises the Automato Network Name as an mDNS hostname
(e.g., `southknox.local`). The user's browser bookmark works regardless of
which physical board is the current gateway. mDNS TTL is short — re-resolves
automatically within ~60 seconds of a gateway change.

**Individual board access:**
Every board on WiFi remains accessible at `boardname.local` independently.
If a board moves out of mesh range but reconnects to WiFi, it is immediately
reachable at its own address.

**1-hop relay:**
Boards out of WiFi range but within ESP-NOW range of the gateway (or another
WiFi-connected board) relay their sensor data through that board. Commands
from the dashboard relay back the same path.

**Graceful degradation when a board moves:**

| Board state | Behaviour |
|---|---|
| On WiFi | Reachable at `boardname.local`, appears in network dashboard |
| ESP-NOW range only (1 hop) | Data relayed through nearest peer, visible in dashboard |
| Completely isolated | Tier 3 rules run independently; rejoins automatically when back in range |

### v1.3 Target — Multi-Hop Relay + Routing Tables

```
Router <─WiFi─> Board 1 <─ESP-NOW─> Board 2 <─ESP-NOW─> Board 4
                        <─ESP-NOW─> Board 3 <─ESP-NOW─> Board 4 (after move)
```

Board 4 moves from Board 2's range to Board 3's range. The routing table
updates within one beacon cycle. Board 4 remains visible in the dashboard
throughout, briefly showing "reconnecting" during the transition.

**Packet structure:**
```cpp
typedef struct {
  uint8_t  type;
  uint8_t  originMac[6]; // originating board — used for duplicate-drop
  uint16_t seq;          // sequence number per originating board
  uint8_t  ttl;          // decrements each hop; dropped at 0
  uint8_t  payload[];
} MeshPacket;
```

**Duplicate-drop:** A board that has already forwarded a given `originMac + seq`
combination drops it immediately. Prevents routing loops.

**TTL guard:** Packets dropped after N hops regardless. Default TTL = 5
(supports a chain of 5 boards — more than any realistic Automato installation).

**Bidirectional relay:** Sensor data flows toward the gateway. Commands
(relay toggle, settings change) flow from the gateway back to the target board
via the same routing path in reverse.

**Routing table updates:** When a board's beacon is received by a new neighbor,
that neighbor propagates a routing update toward the gateway. All intermediate
boards update their tables. Convergence time: 1–3 beacon cycles.

### Network Scale Limits

| Parameter | Value | Notes |
|---|---|---|
| Max ESP-NOW peers per board | 20 | Hard limit in ESP-NOW stack |
| Max boards in direct star | 21 | 1 gateway + 20 direct peers |
| Max boards with 1 relay tier | ~50–80 | Practical limit with routing overhead |
| Max boards with 2 relay tiers | ~150–200 | Well beyond any realistic installation |
| Max hops | 5 (TTL default) | Configurable |
| Transition time after board moves | 1–3 beacon cycles | Seconds to ~1 minute |

For virtually all Automato installations (2–15 boards), no limit is approached.

### Why Not ESP-Mesh-Lite or Other Mesh Libraries

| Option | Verdict | Reason |
|---|---|---|
| ESP-Mesh-Lite | ❌ | ESP-IDF 5.x only — no Arduino framework support. Would require abandoning Arduino IDE, breaking the plugin hook architecture and webapp-only deploy workflow. |
| painlessMesh | ❌ | Requires arduino-esp32 v2.0.x; ESP32-C6 requires v3.x. Mutually exclusive. |
| zh_network | ❌ | ESP32-C6 unverified; tested on PlatformIO only, not Arduino IDE. |
| Thread/OpenThread | ⏳ | Correct protocol for large IoT mesh; ESP32-C6 hardware supports it. Deferred — requires ESP-IDF, steep ramp-up, needs a Border Router. Revisit at v2.0. |
| Custom ESP-NOW | ✅ | Arduino-native, fully verified on ESP32-C6, no external dependencies, no maintenance treadmill, right-sized for Automato's actual use case. |

**The fundamental constraint:** any external mesh library introduces an update
dependency. When the library or its underlying ESP-IDF changes, firmware must
update or break. The most robust firmware owns everything it depends on.
Custom ESP-NOW code, once written, is stable indefinitely.

---

## Known Decisions and Rationale

| Decision | Rationale |
|---|---|
| TCA9534 address is 0x27 (not 0x20) | SparkFun Qwiic GPIO has all address jumpers bridged by default |
| ESP-NOW LR on AP interface only | Setting LR on STA before WiFi connects breaks connection |
| Highest priority rule wins conflicts | Industry standard. Enables safety override rules. |
| Failsafe state is jumper-selectable (next revision) | Agricultural failure modes are asymmetric — installer decides, not firmware |
| Browser-side external API calls | Keeps firmware lean; no API keys stored on device |
| Phase 1 platform = cloud relay, not cloud compile | Remote viewing benefits every user; cloud compile is a developer feature |
| No user accounts on automato.ag | Privacy-first; cloud identity derived from Network Name + password locally |
| Monaco Editor for cloud IDE | Same engine as VS Code — familiar, powerful, well maintained |
| Base firmware pre-installed at shipping | Users functional out of box, no tools required |
| Offline webapp on LittleFS | Updatable independently of firmware; scales beyond PROGMEM limits |
| AP mode on first boot | True zero-infrastructure setup — works anywhere, no router required |
| Stem cell architecture | Stable base + specialised OTA overlays = safe, flexible, maintainable |
| Plugin hook via weak functions + custom.ino | Intermediate users extend without forking; base firmware updates are non-breaking |
| MicroSD slot on next Brain Board revision | IO18–IO21 are unconnected on V2.0; ~$0.40–$0.60 BOM; enables always-on local logging |
| EX-01 is optional, not required | Only needed for >8 board types or >1 of same type per bus |
| Third-party I2C devices are first-class | Automato is explicitly non-proprietary |
| No external mesh library | External libraries introduce update dependencies — firmware must update when library or underlying IDF changes. Custom ESP-NOW code is stable indefinitely. |
| Every board is a full peer | Boards move with plants and seasons. Fixed Host/Remote roles require manual reconfiguration on every move. Dynamic gateway election eliminates this friction. |
| Dynamic gateway election | Whichever board has active WiFi router connectivity becomes the gateway. Changes automatically when boards move. User's bookmark (`networkname.local`) never breaks. |
| `networkname.local` mDNS | Gateway advertises Network Name as mDNS hostname. User always reaches the network at the same address regardless of which physical board is currently the gateway. |
| Multi-hop via custom relay (v1.3) | Boards may be out of WiFi range but within ESP-NOW range of another board. TTL + message-ID duplicate-drop prevents routing loops. Routing tables update within 1–3 beacon cycles when boards move. |
| Board mobility is a first-class use case | Boards follow plants, pots, and seasons. Architecture must self-organize around this without requiring user reconfiguration. |

---

## Version History Summary

| Version | Key Feature |
|---|---|
| v0.1 | Single-board sensor dashboard |
| v0.2 | Two-board ESP-NOW LR |
| v0.3 | ESP-IDF v5.5+ callback fix |
| v0.4 | WiFi + LR coexistence fix |
| v0.5 | Agri Data sidebar |
| v0.6 | Manual relay control (Qwiic GPIO) |
| v0.6.1 | TCA9534 address fix (0x20 → 0x27) |
| v0.7 | OTA firmware update + LittleFS migration |
| v0.8 | WiFi provisioning, captive portal, mDNS, channel scan |
| v0.8.1 | Tab nav shell, I2C Scanner tab, `/i2c-scan` endpoint ✅ |
| v0.9 | Devices tab, remote I2C scan via ESP-NOW, Automato Network Name | ✅ |
| v1.0 | Settings tab, Network tab stub, `POST /settings` endpoint | ✅ |
| v1.1 | Unified firmware, MSG_HELLO auto-discovery, dynamic gateway, `networkname.local`, 1-hop relay, plugin hooks, /proxy, /prefs, agri sidebar phases 1–5b | ✅ |
| v1.2 | Rules tab, firmware rule engine, recipe database — stable, shippable |
| v1.3 | Multi-hop relay, routing tables, full peer equality, cross-board rules |

---

## ESP32-C6 Unexplored Capabilities

The Brain Board's ESP32-C6 contains hardware features not yet used in current firmware.
Full details in [`docs/ESP32C6_Capabilities.md`](ESP32C6_Capabilities.md).

| Capability | Agricultural Relevance | Roadmap Status |
|---|---|---|
| LP (Low-Power) Co-Processor | Run Tier 3 rules while HP core sleeps — enables battery deployment | Future |
| Wi-Fi 6 TWT | Scheduled radio wake windows — extends battery life on remote nodes | Future |
| Bluetooth 5 LE | Phone-based provisioning, BLE sensor beacon, WiFi-down fallback | Planned |
| Zigbee 3.0 / Thread 1.3 | Alternative mesh transport for large deployments (>50 boards, requires ESP-IDF) | Deferred to v2.0+ |
| Die Temperature Sensor | MCU health diagnostic, zero additional hardware | Done (v0.8.1) |
| Hardware Crypto Accelerators | Practical HTTPS to automato.ag, secure boot for production | Phase 1 |
| Hardware PWM | Richer LED status, buzzer, motor/dimmer control | Future |
| Hardware Pulse Counter (PCNT) | Flow meters, anemometers, rain gauges | Future |

Note: LP core, TWT, and 802.15.4 require ESP-IDF, not the Arduino framework.
Arduino is retained permanently for the plugin hook architecture (`custom.ino`),
webapp-only deploy workflow, and DIY-first accessibility. ESP-IDF features that
require abandoning Arduino are deferred until a migration path exists that
preserves these properties.

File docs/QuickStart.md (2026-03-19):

# Quick Start Guide

## What You Need

- 2× Automato Brain Board V2.0
- USB-C cables for both boards
- A 2.4 GHz WiFi network (WPA2)
- Arduino IDE 2.x with the Automato board package installed

---

## Step 1 — Install Libraries

Open Arduino IDE → **Tools → Manage Libraries** and install:

- `Adafruit SHTC3 Library`
- `Adafruit TSL2591`
- `SparkFun TCA9534` *(for relay control — install even if you don't have the hardware yet)*

Accept all dependency installs (Adafruit BusIO, Adafruit Unified Sensor).

---

## Step 2 — Flash Board 1 (Host)

1. Connect Board 1 via USB-C
2. Select **Automato Brain Board V2.0** in Arduino IDE
3. Open `firmware/BrainBoard_Host/BrainBoard_Host_v08/BrainBoard_Host_v08.ino`
4. Click **Upload**
5. Open **Serial Monitor** at **115200 baud** and press **RESET**

---

## Step 3 — Provision WiFi

On first boot (or after a credential reset), Board 1 enters provisioning mode.

1. On your phone or laptop, connect to the WiFi network **`Automato-XXXX`** (where XXXX is the last 4 characters of the board's MAC address)
2. A setup page should open automatically. If not, navigate to **`http://192.168.4.1`**
3. Enter your home WiFi **SSID** and **password**
4. Optionally set a **board name** (used as the mDNS hostname — letters, numbers, spaces, hyphens only)
5. Click **Save & Connect**
6. The board will reboot and join your WiFi network

> 💡 Credentials are stored in NVS and survive reboots and OTA updates. You only need to do this once.

---

## Step 4 — Find Board 1 on Your Network

After provisioning, Board 1 is reachable at:

- **`http://boardname.local`** — if you set a board name (e.g. `http://greenhouse.local`)
- **`http://automato-XXXX.local`** — if no board name was set
- **`http://<IP address>`** — IP is printed in Serial Monitor at startup

---

## Step 5 — Flash Board 2 (Remote)

1. Open `firmware/BrainBoard_Remote/BrainBoard_Remote_v05/BrainBoard_Remote_v05.ino`
2. Find Board 1's MAC address — it's printed in Serial Monitor at startup
3. Paste it into the sketch:

```cpp
uint8_t HOST_MAC_ADDRESS[] = {0xE4, 0xB3, 0x23, 0x89, 0x7E, 0x20};
```

4. Connect Board 2 via USB-C and upload the sketch
5. Open Serial Monitor — you should see Board 2 scanning channels and locking on:

```
Scanning channels 1–13 for Board 1...
  Channel 1... no response.
  Channel 6... ACK! Locking to channel 6.
Ready. Sending every 3000 ms on channel 6.
```

> Board 2 automatically finds the correct WiFi channel. If the channel ever changes, it re-scans after 30 seconds of silence.

---

## Step 6 — Open the Dashboard

Navigate to Board 1's address in any browser on the same WiFi network.

You should see:
- **Board 1** sensor readings (live)
- **Board 2** sensor readings with link status badge
- **Relay Control** panel in the sidebar (if Qwiic GPIO is connected)
- **Agri Data** sidebar (enter a location to load external data)

---

## Relay Control (Optional)

Requires a **SparkFun Qwiic GPIO (TCA9534)** connected to Board 1's Qwiic port.

1. Connect Qwiic GPIO to either Qwiic port on Board 1
2. Wire relay board IN to Qwiic GPIO pin 0
3. Power relay board from USB hub (5V)
4. Reset Board 1 — TCA9534 will be detected automatically
5. Use ON/OFF buttons in the dashboard Relay Control panel

If the Qwiic GPIO is not connected, a warning banner appears but everything else works normally.

---

## Resetting WiFi Credentials

To clear stored credentials and re-enter provisioning mode:

1. With Board 1 connected to power, press and **hold the BOOT button (IO9)**
2. While holding BOOT, press and release **RESET**
3. Keep holding BOOT for **5–7 seconds** after the reset
4. Release — Board 1 will clear its credentials and restart in provisioning mode

---

## Troubleshooting

| Problem | Fix |
|---|---|
| `Automato-XXXX` WiFi not visible | Board may be connected to a saved network. Do a credential reset (see above). |
| Setup page doesn't open automatically | Navigate manually to `http://192.168.4.1` while connected to `Automato-XXXX`. |
| `boardname.local` not resolving | mDNS can be unreliable on some Windows networks. Use the IP address instead (printed in Serial Monitor). |
| Board 2 stuck scanning channels | Confirm Board 1 is powered and running v0.8. Confirm the MAC address in the Remote sketch is correct. |
| Board 2 shows "Signal lost" | Board 2 may be powered off or out of range. Stale timeout is 15 seconds. Board 2 will re-scan channels automatically. |
| Relay GPIO warning showing | TCA9534 not detected on I2C. Check Qwiic cable seating. |
| Dashboard won't load | Confirm you're on the same WiFi network as Board 1. |

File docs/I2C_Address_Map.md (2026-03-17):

# Automato I2C Address Map

Last updated: 2026-03-17

This is a living document. Every I2C device across the entire Automato product
family is tracked here. **This document must be consulted before finalising any
PCB design.** Changing an I2C address after a PCB is manufactured requires
cutting traces or adding wire jumpers.

---

## How to Use This Document

Before adding any I2C chip to a new PCB design:
1. Check the Reserved Addresses table — confirm the address is not already taken
2. Check the Known Conflicts table — confirm no conflict with Brain Board onboard devices
3. Add the new device to the Full Address Allocation table
4. Note whether the address is fixed or configurable

---

## Brain Board Onboard Devices (permanent constraints)

These addresses are fixed or reserved on the Brain Board PCB. Every product in the
Automato ecosystem must work around them.

| Device | Address | Fixed? | Notes |
|---|---|---|---|
| SHTC3 (temp/humidity) | 0x70 | YES — hardcoded | Cannot be changed. High conflict risk. |
| TSL2591 (light) | 0x29 | YES — hardcoded | Cannot be changed. |
| DS3231 (RTC) | 0x68 | YES — hardcoded | Added to Brain Board in next revision. Do not assign other devices to 0x68. |

> ⚠️ 0x70 is a high-risk address. The TCA9548A I2C multiplexer defaults to 0x70.
> Any Automato product using a TCA9548A must configure it to 0x71 or higher.
> Any peripheral board using a chip that can be at 0x70 must ship with that chip
> at a different address.

---

## Reserved Address Blocks

These ranges are reserved for specific Automato purposes.
Do not assign other devices to these addresses.

| Address Range | Reserved For | Notes |
|---|---|---|
| 0x29 | TSL2591 (Brain Board onboard) | Fixed — do not use |
| 0x68 | DS3231 RTC (Brain Board onboard) | Fixed — do not use |
| 0x50 | Self-ID EEPROM — Brain Board Solo (BB-01) | AT24C02 |
| 0x51 | Self-ID EEPROM — AC Relay Board (AC-01) | AT24C02 |
| 0x52 | Self-ID EEPROM — AC Wall Plug (AC-02) | AT24C02 |
| 0x53 | Self-ID EEPROM — DC MOSFET Board (DC-01) | AT24C02 |
| 0x54 | Self-ID EEPROM — DC Relay Board (DC-02) | AT24C02 |
| 0x55 | Self-ID EEPROM — Motion Control Board (DC-03) | AT24C02 |
| 0x56 | Self-ID EEPROM — Battery Management (DC-04) | AT24C02 |
| 0x57 | Self-ID EEPROM — RS-485 Board (CN-01) | AT24C02 |
| 0x70 | SHTC3 (Brain Board onboard) | Fixed — do not use |

> Note: AT24C02 supports addresses 0x50–0x57 (8 addresses total, one per board type).
> If more than 8 board types need self-identification EEPROMs, use a different EEPROM
> chip with a different base address, or use the I2C Hub to isolate EEPROM buses.

---

## Full Address Allocation Table

### 0x00 – 0x0F (Reserved by I2C specification)
Do not use.

### 0x10 – 0x1F

| Address | Device | Product | Configurable? | Notes |
|---|---|---|---|---|
| 0x10 | — | — | — | Available |
| 0x11 | — | — | — | Available |
| 0x12–0x1F | — | — | — | Available |

### 0x20 – 0x2F

| Address | Device | Product | Configurable? | Notes |
|---|---|---|---|---|
| 0x20 | TCA9534 GPIO expander | BB-02 / AC-01 / DC-01 | YES (A0-A2) | Default if all jumpers open. Our boards ship at 0x27 (all bridged) |
| 0x21 | TCA9534 variant | Expansion | YES | Available if needed |
| 0x22 | TCA9534 variant | Expansion | YES | Available if needed |
| 0x23 | TCA9534 variant | Expansion | YES | Available if needed |
| 0x24 | TCA9534 variant | Expansion | YES | Available if needed |
| 0x25 | TCA9534 variant | Expansion | YES | Available if needed |
| 0x26 | TCA9534 variant | Expansion | YES | Available if needed |
| 0x27 | TCA9534 GPIO expander | Current (SparkFun Qwiic GPIO) | YES | All address jumpers bridged — current hardware default |
| 0x28–0x2F | — | — | — | Available |

### 0x30 – 0x3F

| Address | Device | Product | Configurable? | Notes |
|---|---|---|---|---|
| 0x30–0x3B | — | — | — | Available |
| 0x3C | SSD1306 OLED display | BB-03 | Limited (0x3C or 0x3D) | Default OLED address |
| 0x3D | SSD1306 OLED display alt | BB-03 alt | Limited | Alternate OLED address |
| 0x3E–0x3F | — | — | — | Available |

### 0x40 – 0x4F

| Address | Device | Product | Configurable? | Notes |
|---|---|---|---|---|
| 0x40 | INA219 current monitor | AC-01/DC-01/DC-02/EX-02 ch1 | YES (A0-A1) | 4 possible addresses 0x40–0x43. Default 0x40. |
| 0x41 | INA219 current monitor | ch2 | YES | |
| 0x42 | INA219 current monitor | ch3 | YES | |
| 0x43 | INA219 current monitor | ch4 | YES | |
| 0x44–0x47 | INA219 variants | Expansion | YES | Soft reserve for additional INA219 channels |
| 0x40 | HDC1080 humidity sensor | EX-03 | Fixed at 0x40 | CONFLICT RISK with INA219 — use I2C Hub if both needed |
| 0x48 | ADS1115 ADC | EX-03 (soil moisture, EC) | YES (A0 pin) | 4 addresses: 0x48–0x4B |
| 0x49 | ADS1115 ADC alt | EX-03 alt channel | YES | |
| 0x4A–0x4B | ADS1115 variants | Expansion | YES | |

> **INA219 vs INA260:** INA219 (~$1.50 each) selected over INA260 (~$5.58 each).
> On a 4-channel board INA219 adds ~$6 to BOM vs ~$22 for INA260.
> INA219 accuracy is sufficient for agricultural load fault detection.
> INA219 uses addresses 0x40–0x43 (4 addresses via A0/A1 pins).
> INA260 uses 0x40–0x4F (16 addresses) — not needed for current lineup.

> ⚠️ CONFLICT: HDC1080 (0x40 fixed) conflicts with INA219 at default address 0x40.
> If both EX-03 and a power board with INA219 are on the same bus, configure
> INA219 to 0x41+ OR use I2C Hub to isolate them on separate channels.

### 0x50 – 0x5F

| Address | Device | Product | Configurable? | Notes |
|---|---|---|---|---|
| 0x50 | AT24C02 Self-ID EEPROM | BB-01 Brain Board Solo | Fixed per board type | RESERVED |
| 0x51 | AT24C02 Self-ID EEPROM | AC-01 AC Relay Board | Fixed per board type | RESERVED |
| 0x52 | AT24C02 Self-ID EEPROM | AC-02 AC Wall Plug | Fixed per board type | RESERVED |
| 0x53 | AT24C02 Self-ID EEPROM | DC-01 DC MOSFET Board | Fixed per board type | RESERVED |
| 0x54 | AT24C02 Self-ID EEPROM | DC-02 DC Relay Board | Fixed per board type | RESERVED |
| 0x55 | AT24C02 Self-ID EEPROM | DC-03 Motion Control Board | Fixed per board type | RESERVED |
| 0x56 | AT24C02 Self-ID EEPROM | DC-04 Battery Management | Fixed per board type | RESERVED |
| 0x57 | AT24C02 Self-ID EEPROM | CN-01 RS-485 Board | Fixed per board type | RESERVED |
| 0x58–0x5F | — | — | — | Available — reserve for future Self-ID EEPROMs |

### 0x60 – 0x6F

| Address | Device | Product | Configurable? | Notes |
|---|---|---|---|---|
| 0x60 | PCA9685 PWM driver | DC-04 Servo Driver | YES (A0-A5) | 64 possible addresses 0x40–0x7F — using 0x60 as default |
| 0x61–0x6F | PCA9685 variants | Expansion | YES | Reserve for additional servo/PWM boards |
| 0x62 | SCD40 CO2 sensor | EX-03 | Fixed at 0x62 | CONFLICT with PCA9685 if PCA9685 configured to 0x62 — avoid |

> Note: PCA9685 has 6 address pins and supports 64 addresses from 0x40–0x7F.
> Configure PCA9685 to avoid 0x40–0x4F (INA260/ADS1115 range) and 0x62 (SCD40).
> 0x60 is a clean default.

### 0x70 – 0x7F

| Address | Device | Product | Configurable? | Notes |
|---|---|---|---|---|
| 0x70 | SHTC3 temp/humidity | Brain Board (onboard) | NO — FIXED | PERMANENT CONSTRAINT |
| 0x71 | TCA9548A I2C Multiplexer | EX-01 I2C Hub | YES (A0-A2) | Configured to 0x71 on PCB — avoids SHTC3 at 0x70 |
| 0x72–0x77 | TCA9548A variants | Expansion | YES | Available for additional Hub boards |
| 0x29 | TSL2591 light sensor | Brain Board (onboard) | NO — FIXED | Listed here for completeness — see 0x20-0x2F range |

---

## Known Conflict Summary

| Conflict | Devices | Resolution |
|---|---|---|
| HIGH RISK | SHTC3 (0x70, fixed) vs TCA9548A default (0x70) | TCA9548A must be configured to 0x71+ on all Automato PCBs |
| HIGH RISK | SHTC3 (0x70, fixed) vs HT16K33 LED driver default (0x70) | Do not use HT16K33 on same bus as Brain Board, or configure to 0x71+ |
| HIGH RISK | DS3231 (0x68, Brain Board onboard) vs MPU6050/ICM-20948 (0x68) | Use I2C Hub to isolate if IMU needed alongside Brain Board |
| MEDIUM RISK | INA219 default (0x40) vs HDC1080 (0x40, fixed) | Use I2C Hub to isolate, or configure INA219 to 0x41+ |
| MEDIUM RISK | SCD40 (0x62, fixed) vs PCA9685 if configured to 0x62 | Configure PCA9685 away from 0x62 |
| LOW RISK | Multiple TCA9534 boards at same address | Set different A0-A2 jumpers per board — up to 8 boards supported |
| LOW RISK | Multiple AT24C02 EEPROMs | Each board type assigned a unique address 0x50–0x57 |

---

## Addresses Available for Future Assignment

The following ranges are currently unallocated and available for new products:

- 0x10–0x1F (16 addresses)
- 0x28–0x2F (8 addresses, excluding TCA9534 variants)
- 0x30–0x3B (12 addresses)
- 0x44–0x47 (4 addresses — soft reserve for INA260 expansion)
- 0x58–0x5F (8 addresses — soft reserve for future Self-ID EEPROMs)
- 0x63–0x6F (13 addresses, excluding SCD40 at 0x62)
- 0x72–0x77 (6 addresses — TCA9548A variants)

---

## DS3231 RTC Note

The DS3231 RTC uses address 0x68 and is now integrated directly onto the Brain
Board PCB (next revision). This means 0x68 is a permanent Brain Board constraint
alongside 0x70 (SHTC3) and 0x29 (TSL2591).

0x68 is also used by several IMUs (MPU6050, ICM-20948) and other RTCs (DS1307,
PCF8523). If any future Automato product uses an IMU, a conflict will occur.
Use the I2C Hub (EX-01) to isolate these devices on separate channels if both
are needed on the same Brain Board.

There is no longer a standalone RTC expansion board (EX-04 removed from lineup).
All Brain Boards include RTC from the next hardware revision.

---

## I2C Hub Usage Guide

When two or more Automato peripheral boards have conflicting I2C addresses,
use the EX-01 I2C Hub board (TCA9548A at 0x71):

1. Connect I2C Hub to Brain Board via 6-pin Automato cable
2. Connect conflicting boards to separate Hub ports
3. Brain Board firmware detects Hub via self-ID EEPROM on boot
4. Firmware automatically manages channel switching transparently
5. User never needs to think about address conflicts

The I2C Hub is not needed for most simple setups. It is an accessory for
complex multi-board installations.

---

## Updating This Document

When adding a new IC to any Automato PCB design:
1. Look up its I2C address(es) in the datasheet
2. Check this document for conflicts
3. Add an entry to the Full Address Allocation Table
4. Update the Known Conflict Summary if applicable
5. Commit the updated document to the Brain-Board repository

Filename: `docs/I2C_Address_Map.md`
Repository: `https://github.com/Automato-ag/Brain-Board`

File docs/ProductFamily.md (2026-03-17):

# Automato Product Family

Last updated: 2026-03-17

This document defines the hardware architecture, connector standard, product lineup,
and design principles for the Automato product family. It is a living document —
updated as products are defined and decisions are made.

---

## Core Architecture Principle

The Brain Board is the computational organ of every Automato product. It is always
a discrete, separate PCB. It is never integrated into another board. In every
product — bundled or standalone — the Brain Board connects to peripheral boards
via the Automato 6-pin connector.

```
Brain Board (always separate)
    │
    │ 6-pin Automato connector (Qwiic-compatible subset)
    │
Peripheral Board(s) — any combination, daisy-chained or hub-connected
```

Any number of peripheral boards can connect to a single Brain Board over the I2C
bus simultaneously. A single enclosure may contain a Brain Board plus multiple
peripheral boards, all connected by 6-pin Automato cables.

---

## The Two Purchasing Paths

**Separate purchase:** Buy a Brain Board and any peripheral board(s) independently.
Connect with a 6-pin Automato cable. Maximum flexibility, repairability, and
upgradeability. Ideal for custom installations, developers, and advanced users.

**Bundled purchase:** Buy a Brain Board and peripheral board(s) pre-assembled inside
an enclosure. The boards inside a bundle are identical to the separately-sold boards,
connected by the same 6-pin Automato cable. Opening the enclosure and replacing one
board is always possible.

The firmware, the ecosystem, and the automato.ag platform behave identically
regardless of which path the user took.

---

## The 6-Pin Automato Connector

**Physical spec:** JST-PH 2.0mm pitch, 6-pin, keyed and polarized.

**Pinout:**

| Pin | Signal | Notes |
|---|---|---|
| 1 | GND | Common ground |
| 2 | 3.3V | Logic power from Brain Board |
| 3 | SDA | I2C data |
| 4 | SCL | I2C clock |
| 5 | INT | Interrupt — peripheral to Brain Board (active LOW) |
| 6 | 5V or 3.3V | Second power rail — defined per board type |

**Backward compatibility:** A 6-pin to 4-pin Qwiic adapter cable allows standard
Qwiic/STEMMA QT sensors to connect to any Automato 6-pin port. Pins 1–4 are
identical to Qwiic. Pins 5 and 6 are unused in Qwiic-adapter mode.

**Protocol:** I2C is the primary communication protocol. All peripheral boards
communicate with the Brain Board over SDA/SCL. Peripheral boards use onboard
I2C chips (GPIO expanders, ADCs, PWM drivers) to translate I2C commands into
the signals needed for their specific function — analog, PWM, relay switching, etc.

**Why 6-pin over 8-pin:** Most peripheral board signal needs (analog, PWM, GPIO)
are better handled by onboard I2C chips than by routing those signals through
the cable. The 6-pin connector carries everything needed for the vast majority
of use cases in a compact, affordable form factor.

---

## Self-Identification

Every peripheral board carries a small I2C EEPROM that stores its board type,
hardware version, and channel count. The Brain Board reads this on boot and
configures itself automatically — no jumpers, no firmware selection, no user
configuration required.

A user plugs in a peripheral board and the Brain Board knows what it is.

**EEPROM standard:** AT24C02 or equivalent, 256 bytes.
**Address allocation:** See `docs/I2C_Address_Map.md` for reserved EEPROM addresses.

---

## Product Lineup

### Brain Board Products

**BB-01 — Brain Board Solo**
Standalone Brain Board for sensor reading and reporting. Onboard SHTC3
(temperature/humidity), TSL2591 (light), DS3231 RTC, WiFi, ESP-NOW, and
automato.ag integration. No relay, no mains power. The simplest product —
connects to any peripheral board via 6-pin Automato connector.

> **Design decision:** DS3231 RTC is included onboard in next Brain Board revision.
> RTC adds ~$3.10 to BOM (DS3231 ~$2.50 + CR2032 holder ~$0.30 + passives ~$0.30).
> Justified because accurate time enables offline rule scheduling on every product
> in the lineup without requiring a separate board.
> DS3231 uses I2C address 0x68 — reserved in I2C Address Map.
> Estimated Brain Board BOM: ~$11.80 (components only, excl. PCB/assembly).

**BB-02 — Brain Board with GPIO Expander**
Brain Board plus a GPIO expander peripheral board (TCA9534 or similar) in a
compact enclosure. Exposes I/O pins for user-provided sensors, switches, and
devices. For advanced users and custom installations.

**BB-03 — Brain Board with Display (Future)**
Brain Board with an I2C OLED or e-ink display in a purpose-built enclosure.
Local sensor data readout without phone or laptop. Display connects via
6-pin Automato connector.

---

### AC Power Control Products

> ⚠️ All AC products involve mains voltage. See Safety section below.

**AC-01 — Smart Power Strip**
Multi-channel AC relay board in a power strip enclosure with integrated Brain Board.
Evolution of the existing Automato Relay Board. Redesigned to use I2C control
(TCA9534 GPIO expander) rather than 74HC595 shift register. Brain Board connects
via 6-pin Automato cable inside enclosure. Relay board sold separately for users
who supply their own Brain Board.

Upgrade notes from existing Relay Board:
- Control interface: 74HC595 SPI-like → TCA9534 I2C (consistent with ecosystem)
- Connector: USB-C control interface → 6-pin Automato
- Self-identification EEPROM added
- Per-channel current sensing via INA219 (see note below)

> **Current sensing decision:** INA219 (~$1.50 each) used instead of INA260
> (~$5.58 each). For 4-channel board: INA219 adds ~$6 to BOM vs ~$22 for INA260.
> INA219 accuracy is sufficient for agricultural load monitoring (pump fault
> detection, heater verification). INA260's higher accuracy and wider voltage
> range are not needed at 120/240VAC relay loads.
> Estimated AC-01 BOM with INA219 current sensing: ~$23 (components only).

**AC-02 — Smart Wall Plug**
Compact wall plug form factor. Brain Board connects via 6-pin Automato cable to
a relay PCB. Relay PCB plugs directly into wall outlet or power strip and exposes
a controlled NEMA 5-15 or NEMA 5-20 receptacle. Single controlled outlet.
Thermal management in sealed enclosure is a key design constraint.

> Note: UL/ETL certification required for commercial sale of mains-connected
> wall plug products in North America. Plan certification process before
> committing to production volumes.

---

### DC Power Control Products

**DC-01 — DC MOSFET / High-Side Switch Board**
Multi-channel MOSFET/high-side switch board for DC loads — solenoids, pumps,
motors, valves, LED lighting. I2C controlled via onboard TCA9534 GPIO expander.
Connects to Brain Board via 6-pin Automato cable.

Notes:
- MOSFETs preferred over relays for inductive DC loads (no contact arc welding)
- PWM capability on each channel via onboard PCA9685
- Freewheeling diodes required on all inductive load channels
- Rated for typical agricultural DC loads: 12V/24V solenoids, 12V pumps
- Per-channel current sensing via INA219
- Estimated BOM with INA219 current sensing: ~$11.61 (components only)

**DC-02 — DC Relay Board**
Multi-channel relay board for DC loads requiring full electrical isolation.
For applications where MOSFET switching is insufficient — high-voltage DC,
mixed signal/power isolation, or user preference.
- Per-channel current sensing via INA219
- Estimated BOM with INA219: ~$18.11 (components only)

**DC-03 — Motion Control Board (Stepper + Servo)**
Consolidated board combining stepper motor driver and PCA9685 servo/PWM driver.
Covers both actuation types on one board — irrigation valve positioning, automated
vents, feeder mechanisms, damper control, and angular positioning applications.

> **Consolidation decision:** Stepper and servo boards merged into one.
> Adding PCA9685 servo capability to the stepper board costs ~$2.25 in BOM.
> A user doing valve actuation may need either a stepper or servo depending on
> valve type — one board covers both. Estimated BOM: ~$8.36 (components only).

**DC-04 — Battery Management Board**
LiPo/LiFePO4 charging, protection, and state-of-charge reporting over I2C.
For battery-powered remote node deployments. Works with LP core deep sleep
architecture for multi-month battery life on remote sensor nodes.
- Estimated BOM: ~$6.05 (components only)

---

### Connectivity Products

**CN-01 — RS-485 / Modbus Board**
MAX3485 or similar transceiver. Screw terminals for RS-485 field cable (A, B, GND).
Termination resistor jumper. Self-identification EEPROM. Connects to Brain Board
via 6-pin Automato cable.

Enables Brain Board compatibility with the large ecosystem of professional
agricultural sensors using Modbus RTU — soil probes, weather stations,
flow meters, irrigation controllers.

**CN-02 — Cellular Board**
LTE Cat-M1/NB-IoT modem (SIM7600 or similar). SIM card slot. Connects to
Brain Board via 6-pin Automato cable. Provides internet connectivity where
WiFi is unavailable — remote field deployments, no local infrastructure required.

Enables Phase 2 cloud relay (automato.ag data relay + remote OTA) without WiFi.
Particularly relevant for Brain Boards running as autonomous remote nodes.

---

### Expansion and Monitoring Products

**EX-01 — I2C Hub Board**
TCA9548A-based 8-channel I2C multiplexer. Connects to Brain Board via 6-pin
Automato cable. Exposes 4 or 8 downstream 6-pin Automato ports.

Solves I2C address conflicts transparently — user plugs conflicting boards into
different Hub ports, firmware handles channel switching automatically.

Note: TCA9548A configured to 0x71 or higher on PCB (0x70 reserved for SHTC3).
Estimated BOM: ~$3.22 (components only).

**EX-02 — Current and Power Monitoring Board**
INA219 per channel, monitoring load current on relay/MOSFET outputs of third-party
or non-Automato boards. Detects failed pumps, burned-out heaters, open circuit
faults, and overloads. Alerts Brain Board via INT line when thresholds exceeded.

> **INA219 vs INA260:** INA219 (~$1.50) used instead of INA260 (~$5.58).
> INA219 accuracy is sufficient for agricultural load monitoring. Current sensing
> is already built into Automato power boards (AC-01, DC-01, DC-02) — this
> standalone board exists for users monitoring loads on third-party hardware.

**EX-03 — Environmental Sensor Expansion Board**
Additional agricultural sensors beyond Brain Board onboard sensors:
- CO2: SCD40 (0x62)
- Barometric pressure: BMP280 (0x76 or 0x77)
- Soil moisture: capacitive sensor with ADS1115 ADC
- EC (electrical conductivity): via ADS1115 or dedicated IC

> **Note:** RTC functionality (DS3231) has been moved onto the Brain Board PCB
> and is no longer a separate expansion board. All Brain Boards include onboard
> RTC from the next hardware revision.

---

## Safety Contract

This contract applies to every Automato product without exception:

> **All outputs (relay contacts, MOSFET channels, motor drivers) default OFF
> under all failure conditions.**
>
> This includes: board power-up before firmware initializes, firmware crash,
> sensor failure, WiFi loss, cloud loss, I2C bus error, and hardware expander
> not detected.
>
> There is no condition under which any output defaults ON.

**Hardware enforcement:** Relay coils and MOSFET gates must be held in the OFF
state by hardware (pull-down resistors to ground) before firmware initializes.
The safety contract must be a hardware guarantee, not only a software guarantee.

**For AC products specifically:**
- Brain Board and mains voltage must never share a PCB
- AC-DC converter (HiLink HLK-PM03 or equivalent) provides isolated 3.3V
- Relay isolation rated minimum 2500VAC coil-to-contact
- Creepage distance minimum 2.5mm at 250VAC
- Fused AC input on all mains-connected products
- Earth connection required on all mains products

---

## Thermal Management

All products in enclosed enclosures — particularly AC-02 (wall plug) and any
product installed in direct sun — require thermal analysis before production:

- HiLink HLK-PM03 dissipates heat in operation
- Brain Board with WiFi active dissipates heat
- Sealed enclosures in direct agricultural sun can exceed 70°C ambient
- Component derating at elevated temperature must be verified against datasheets
- Ventilation slots or thermal mass calculation required for sealed designs

---

## Regulatory Notes

| Product Type | Regulatory Path |
|---|---|
| DC-only products | Lower burden — no mains voltage certification typically required for component-level boards |
| AC products (mains voltage) | UL/ETL listing expected for commercial sale in North America. CE marking for EU. Significant time and cost — plan early. |
| Cellular products | FCC Part 15 / IC certification for RF. Using a pre-certified cellular module simplifies this considerably. |
| Brain Board | FCC Part 15 Class B for WiFi — ESP32-C6 module may carry existing certification depending on module variant. |

**Recommendation:** Develop and validate DC products before pursuing AC product
certification. DC products have lower regulatory burden and directly address
core agricultural use cases (irrigation, pumps, solenoids).

---

## Roadmap Congruence

This product family is consistent with the Brain Board roadmap in the following ways:

- **Stem cell concept** — Brain Board is the universal computational core
- **Offline first** — every product works without internet
- **Safe by default** — safety contract enforced at hardware level
- **Useful out of the box** — self-identification means no configuration required
- **Progressive enhancement** — Phase 2 cloud relay enabled by cellular board
- **I2C Hub** — transparent conflict resolution, no user expertise required
- **Battery Management Board** — enables LP core + deep sleep battery deployment
- **RTC on Brain Board** — every product gets time-based offline rules automatically

The hardware detection layer (Brain Board reads self-identification EEPROM on boot
and configures itself) should be added to the firmware roadmap before v1.0.

---

## Component Cost Summary

BOM costs only — components at ~100 unit volumes. Does not include PCB
fabrication, assembly, connectors, enclosure, or margin.
PCB + assembly adds approximately $8–15 per board at low volumes.

| Product | Est. BOM Cost | Key cost driver |
|---|---|---|
| BB-01 Brain Board (with RTC) | ~$11.80 | ESP32-C6 module ~$3.50 |
| AC-01 Smart Power Strip (4ch + INA219) | ~$23.00 | Relays + HLK-PM03 |
| AC-02 Smart Wall Plug | ~$18.00 | Relay + HLK-PM03 + compact design |
| DC-01 DC MOSFET Board (4ch + INA219) | ~$11.61 | Simple — no mains components |
| DC-02 DC Relay Board (4ch + INA219) | ~$18.11 | Relays dominate cost |
| DC-03 Motion Control (stepper + servo) | ~$8.36 | Consolidation adds only $2.25 vs stepper-only |
| DC-04 Battery Management | ~$6.05 | Charger IC + fuel gauge |
| CN-01 RS-485 / Modbus | ~$2.15 | Very low cost, high ecosystem value |
| CN-02 Cellular | ~$25–40 | Modem IC dominates |
| EX-01 I2C Hub | ~$3.22 | Very low cost accessory |
| EX-02 Current Monitoring (standalone) | ~$8.00 | INA219 × 4 channels |
| EX-03 Environmental Sensor | ~$12–18 | Depends on sensor selection |

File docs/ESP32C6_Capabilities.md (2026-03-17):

# ESP32-C6 — Unexplored Capabilities

The Brain Board's ESP32-C6-MINI-1-N4 contains several hardware features not yet used in current firmware. These are documented here as potential avenues for exploration in future versions.

---

## 1. LP (Low-Power) Co-Processor

The ESP32-C6 contains two completely independent CPUs:

- **HP core** — 160 MHz RISC-V, runs all current Arduino firmware
- **LP core** — 20 MHz RISC-V, can run independently while HP core sleeps

The LP core can read I2C sensors (including the onboard SHTC3 and TSL2591), monitor GPIO, evaluate threshold conditions, and wake the HP core only when action is required. Measured power consumption drops from ~22 mA (HP active) to ~3 mA (LP only) — roughly an order of magnitude.

**Relevance to Brain Board:** The Tier 3 offline rule engine (currently planned for `loop()` on the HP core in Stage 2) could eventually run entirely on the LP core. The HP core would only wake for WiFi transmission or relay actuation. This is the architecture that enables serious unattended battery-powered field deployment — a sensor node running for months on a battery, waking only when a rule condition is met.

**Connection to the roadmap:**
The Stage 2 Tier 3 rule engine will be written for the HP core in Arduino first. This is the right approach for development speed and testability. However, the rule engine should be designed with LP core migration in mind — keeping rule evaluation logic simple, stateless, and data-structure-focused so it can be ported later without a full rewrite.

**The Arduino/ESP-IDF decision point:**
LP core programming requires ESP-IDF, not the Arduino framework. This is a significant architectural decision that will need to be made before v1.0 ships as a production base firmware:

| Approach | Pros | Cons |
|---|---|---|
| Stay on Arduino, HP core only | Fast development, large community, easy OTA | 22mA always-on, no battery viability |
| ESP-IDF for LP core features only | LP core + HP core Arduino hybrid is possible | Increased complexity, mixed toolchain |
| Full ESP-IDF migration | Access to all low-level features | Major rewrite, loses Arduino ecosystem |

The recommended path is a **hybrid approach** — keep the Arduino framework for the main application on the HP core, and add ESP-IDF ULP/LP core code only for the specific sleep-and-sense loop. Espressif supports this pattern and provides examples. This decision does not need to be made now but should be made before designing the production battery-powered remote node.

**Caveat:** LP core programming requires ESP-IDF, not the Arduino framework. Official Espressif examples include reading an I2C light sensor while HP is in deep sleep and waking HP when a threshold is exceeded — essentially the Brain Board's exact hardware setup.

- ESP-IDF docs: [ULP LP-Core Coprocessor Programming](https://docs.espressif.com/projects/esp-idf/en/stable/esp32c6/api-reference/system/ulp-lp-core.html)

---

## 2. Wi-Fi 6 Target Wake Time (TWT)

The Brain Board uses Wi-Fi 6 (802.11ax). TWT is a Wi-Fi 6 feature that lets a device negotiate a fixed schedule with the router: "I will transmit every 30 seconds at these exact intervals — keep the radio off otherwise." Between scheduled windows the radio is truly powered down.

**Relevance to Brain Board:** The Remote board (Board 2) currently transmits via ESP-NOW every 3 seconds regardless. A future battery-powered remote node using TWT over WiFi instead could negotiate a much longer sleep interval while remaining connected, potentially extending battery life by up to 67%.

**Caveat:** Both the board *and* the router must support Wi-Fi 6 TWT. Requires ESP-IDF Wi-Fi driver configuration, not the standard Arduino WiFi library.

---

## 3. Bluetooth 5 LE

BLE is active silicon on the C6 but unused in current firmware. Four practical use cases for the Brain Board:

**Configuration interface:** A BLE GATT server would let you configure WiFi credentials, offline rules, and thresholds from a phone app before the board is connected to WiFi — the same pattern used by most commercial IoT products. This is the planned first-boot provisioning path for the base firmware (replacing or supplementing the AP mode WiFi setup page).

**Passive sensor beacon:** The board can broadcast sensor readings via BLE advertisement packets simultaneously with serving the WiFi dashboard. Readings become visible to any phone within Bluetooth range without opening a browser, entering credentials, or being on the same WiFi network. This is directly relevant to the offline webapp concept — a user walking through a field could see live readings from any Brain Board simply by having Bluetooth on their phone enabled. No app required for basic readings; a dedicated app could provide richer interaction.

**WiFi-down fallback:** If the router is unavailable, a phone app could poll sensors directly over BLE even when the dashboard is unreachable. Combined with the Tier 3 offline rule engine, this means a board can continue operating and reporting locally even with no network connectivity of any kind.

**Long-range coded PHY:** Bluetooth 5 LE supports a long-range coded PHY mode that significantly extends BLE range at the cost of throughput — useful for sensor nodes at the edge of WiFi coverage where full WiFi connection is not practical but periodic status updates are needed.

**Caveat:** BLE and WiFi share the antenna on the ESP32-C6. Simultaneous operation is supported via coexistence firmware but involves time-slicing the radio, which reduces effective throughput of both. For most agricultural sensor use cases this tradeoff is acceptable.

---

## 4. Zigbee 3.0 / Thread 1.3 (IEEE 802.15.4)

The same radio that handles Wi-Fi and BLE can also run Zigbee 3.0 or Thread 1.3.

**Relevance to Brain Board:** Multiple remote sensor nodes could form a Thread or Zigbee mesh and route data back to a Host board acting as a border router, which then bridges to WiFi. This scales better than ESP-NOW for deployments with many boards spread across large areas.

**Important clarification on accessibility:** The Automato Arduino board package already includes Zigbee mode options in the Arduino IDE Tools menu. This means basic Zigbee functionality may be accessible within the Arduino framework sooner than previously assumed — it does not necessarily require a full ESP-IDF migration. Thread support is less mature in the Arduino layer and more likely to require ESP-IDF.

**Comparison to ESP-Mesh-Lite (the current planned mesh solution):**

| | ESP-Mesh-Lite | Zigbee / Thread |
|---|---|---|
| Protocol | WiFi | IEEE 802.15.4 |
| Throughput | High | Low |
| Power consumption | Higher | Lower |
| Arduino support | Requires verification | Zigbee in board menu |
| Range per hop | ~100m | ~50–100m |
| Agricultural targeting | Espressif listed use case | Industry standard |

ESP-Mesh-Lite is the current planned path due to higher throughput and explicit smart agriculture targeting. Zigbee/Thread remains a strong alternative for battery-powered deployments where low power outweighs throughput needs.

**Caveat:** Wi-Fi, BLE, and 802.15.4 share the same antenna and cannot all run simultaneously at full capacity. Espressif provides coexistence firmware, but configuration and throughput tradeoffs apply. Running Zigbee/Thread means WiFi and BLE capability is reduced or disabled.

---

## 5. Onboard Die Temperature Sensor

The ESP32-C6 has a hardware temperature sensor built into the chip silicon, separate from the SHTC3. It measures the die temperature of the MCU itself.

**Relevance to Brain Board:** Useful as a diagnostic — elevated die temperature relative to ambient indicates heavy CPU or radio load. Accessible in Arduino with a single call: `temperatureRead()`. Zero additional hardware required.

**This is an immediate easy win.** It should be added to the `/data` JSON endpoint and displayed on the dashboard as a board health indicator in a near-term firmware version. The value is most meaningful when compared against the ambient temperature from the SHTC3 — a die temperature significantly above ambient is a useful early warning of thermal stress, particularly in enclosures in direct sun.

---

## 6. Hardware Crypto Accelerators

The C6 includes hardware acceleration for AES, SHA, RSA, and ECC — the operations that make TLS/HTTPS expensive on software-only microcontrollers.

**Relevance to Brain Board:** When the board communicates with the automato.ag cloud relay, HTTPS is practical without significant performance impact. Also enables Flash Encryption and Secure Boot for production deployments — preventing firmware and credential extraction from a board that is physically obtained. These are one-time production-hardening steps (irreversible once enabled) to be considered before shipping boards to customers.

---

## 7. Hardware PWM (LED Controller)

Six independent hardware PWM channels at 14-bit resolution, accessible via `analogWrite()` or the Arduino LEDC library.

**Relevance to Brain Board:** The three onboard LEDs (red IO22, blue IO23, green) could use breathing/pulsing animations as richer status indicators rather than on/off. Also applicable to buzzer tones, motor speed control, or dimming any load on a relay.

---

## 8. Hardware Pulse Counter (PCNT)

A hardware peripheral that counts digital input transitions independently of the CPU — no polling, no missed counts, works while the CPU is sleeping.

**Relevance to Brain Board:** Directly applicable to common agricultural sensors:

| Sensor Type | What It Counts |
|---|---|
| Flow meter | Pulses → water volume delivered to irrigation |
| Anemometer | Pulses → wind speed |
| Rain gauge (tipping bucket) | Pulses → rainfall (typically 0.2 mm per tip) |

These sensors are standard in precision agriculture. Currently, integrating them would require polling a GPIO (burning CPU time) or risking missed pulses during sleep. The hardware counter handles all of this for free.

**Connection to battery deployment and LP core:** The PCNT and LP core are natural partners. The LP core can monitor the pulse counter and accumulate counts while the HP core sleeps, waking the HP core only to transmit accumulated data or when a threshold is exceeded (e.g. a flow meter detects unexpected irrigation activity at night). This combination — PCNT + LP core + deep sleep — is the architecture for a truly low-power agricultural sensor node that can run for months on battery while counting every raindrop and every litre of water delivered.

This should be considered when designing the Qwiic sensor expansion story for the Brain Board, and when planning which sensors are appropriate for battery-powered remote nodes versus mains-powered host nodes.

---

*For current firmware features and roadmap, see the [main README](../README.md).*

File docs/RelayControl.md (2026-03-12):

# Relay Control

## Overview

Brain Board relay control uses a **SparkFun Qwiic GPIO (TCA9534)** I2C expander connected via the Qwiic port, driving an optoisolated relay board. The Brain Board's 3.3V I2C signal is sufficient to trigger the optocoupler on the relay board; the relay coil is powered independently at 5V.

---

## Hardware

| Component | Details |
|---|---|
| GPIO Expander | SparkFun Qwiic GPIO — TCA9534 |
| I2C Address | 0x20 (all address pins LOW) |
| Relay Board | Amazon B0CHFJSNP6 (5V coil, optoisolated, active HIGH) |
| Connection | Qwiic port J2 or J3 on Brain Board |

### Wiring Diagram

```
Brain Board
  Qwiic J2/J3 ──► SparkFun Qwiic GPIO (TCA9534)
                        Pin 0 ──────────────────► Relay Board IN
                        GND ────────────────────► Relay Board GND

USB Hub
  Port A ──► Brain Board USB-C      (3.3V logic)
  Port B ──► Relay Board USB-C      (5V coil power)
  (shared ground via hub — safe, no ground loop)
```

---

## Relay Safety Behavior

The relay **always defaults OFF**. This is enforced at every level:

| Condition | Relay State |
|---|---|
| Board powering up (before init) | OFF |
| TCA9534 not found on I2C | OFF (no-op, warning shown) |
| Sensor read failure | OFF |
| WiFi disconnected | OFF |
| No automation rules active | OFF |
| Manual override active | Follows dashboard toggle |

There is no condition under which a relay defaults ON.

---

## HTTP Endpoints

### `GET /relay?state=1`
Turn relay ON (sets manual override).

**Response:**
```json
{ "ok": true, "manualOverride": true, "state": true }
```

### `GET /relay?state=0`
Turn relay OFF (sets manual override).

**Response:**
```json
{ "ok": true, "manualOverride": true, "state": false }
```

### `GET /relay?override=auto`
Clear manual override — hand control to rule engine (Stage 2+).
Relay defaults OFF until first rule evaluation.

**Response:**
```json
{ "ok": true, "manualOverride": false, "state": false }
```

### `GET /relay/status`
Get current relay state.

**Response:**
```json
{ "state": false, "manualOverride": true, "gpioOk": true }
```

The `/data` endpoint also includes a `relay` object on every poll, keeping the dashboard in sync automatically.

---

## Automation Architecture (Roadmap)

Relay control is designed in three tiers:

| Tier | Location | Requires | Status |
|---|---|---|---|
| 1 — Cloud | automato.ag server | Internet | Planned |
| 2 — Browser | Dashboard tab | Local network + open browser | Planned |
| 3 — On-board | Brain Board NVS | Nothing (fully offline) | Next (Stage 2) |

**Failover order:** Cloud → Browser → On-board offline rules

### Rule Engine Design

Already stubbed in firmware (`BrainBoard_Host_v0.6.ino`):

- Each rule has a name, priority, logic operator, target relay(s), and up to 16 conditions
- Conditions compare sensor values (above/below/equals threshold)
- Logic operators: AND, OR, NOT, XOR
- **Conflict resolution: highest priority rule wins** (priority 1 = highest)
- If no rules fire, relay defaults OFF
- Manual dashboard toggle always overrides all rules regardless of priority

The `evaluateRules()` function is present but commented out in `loop()` — it activates in Stage 2.

---

## Dashboard UI

The **Relay Control** panel is a collapsible section at the top of the sidebar.

- **Dot indicator** — amber pulsing = ON, grey = OFF (visible without opening panel)
- **State badge** — ON / OFF with color coding
- **Mode badge** — Manual / Auto
- **ON / OFF buttons** — manual control
- **GPIO warning** — appears if TCA9534 not detected on I2C bus

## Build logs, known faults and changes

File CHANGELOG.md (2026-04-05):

# Changelog

All notable changes to Brain Board firmware are documented here.

---

## v1.1 — 2026-04-05

Two-board hardware test confirmed 2026-03-28. All items below shipped and tested.

### Firmware (`BrainBoard_v110.ino`)

- **Unified firmware** — `BrainBoard_Host` and `BrainBoard_Remote` merged into single `BrainBoard` firmware; all boards are identical peers; role (gateway / relay / isolated) determined dynamically at runtime
- **MSG_HELLO beacon** — boards broadcast Network Name + board name + MAC + hasWiFi on startup and periodically; matching boards auto-register as ESP-NOW peers without manual MAC entry
- **Dynamic gateway election** — board with active WiFi router connection becomes gateway; strongest RSSI wins if multiple candidates; transfers automatically when boards move
- **`networkname.local` mDNS** — gateway advertises Automato Network Name as mDNS hostname; user bookmark works regardless of which physical board is currently gateway
- **1-hop relay** — non-WiFi boards seek mesh channel via channel scan, lock on first matching MSG_HELLO, relay sensor data to gateway via ESP-NOW
- **NTP time sync** — gateway syncs time on WiFi connect; `POST /time` endpoint allows browser to sync board time
- **Plugin hook architecture** — `customSetup()`, `customLoop()`, `customDataJSON()` weak functions; user adds `custom.ino` to sketch folder without modifying base firmware
- **`/proxy` endpoint** — board-side HTTPS relay for external API calls; 7-domain allowlist (Open-Meteo forecast + ERA5 archive, Geocoding, AQI, Sunrise-Sunset, USNO, NWS); enables agri data when browser has no direct internet (SoftAP field access)
- **`/peers` endpoint** — returns full peer list as JSON including board names, MACs, roles, RSSI, and last-seen timestamps
- **`/prefs` GET/POST** — LittleFS-backed dashboard preference storage; dual-write to NVS as backup (survives LittleFS uploads); GET auto-restores from NVS if file missing
- **SoftAP captive portal fix** — `onNotFound` redirects to `/` (dashboard) when provisioned; `/setup` when not yet provisioned; phone connecting to board SoftAP in the field auto-opens dashboard
- **SoftAP password** — `WiFi.softAP()` called with Network Password; SoftAP is secured when Network Password is set

### Webapp (`data/index.html`)

**Dashboard**
- Board role indicator (Gateway / Relay / Isolated) in tab nav bar
- Board 2 column populated from `/peers` response — board name, sensor readings, link status, last-seen timestamp
- Card visibility per board — toggle individual sensor cards on/off; persisted to `/prefs`

**Settings tab redesign** — three-level navigation:
- Display & Behavior: units toggle (metric/imperial), refresh rate selector (2.5/5/10/30s), auto-sync time on connect, font scale controls, tooltip toggle
- Agri Data Sources: per-source and per-parameter enable/disable with bulk checkboxes
- Board Settings: master-detail layout; local board editable; peer board read-only; DLI crop preset selector and GDD/chill season settings per board

**Network tab** — live peer map; board roles, relay paths, gateway address, WiFi status

**Agri Data sidebar — all phases:**
- Phase 1: weather (temp, precipitation, wind, cloud cover, humidity)
- Phase 2: solar (UV, shortwave, sunrise/sunset/day length, first/last light, solar noon)
- Phase 3: soil (temperature 0–7cm / 7–28cm, moisture, ET₀, VPD)
- Phase 4: moon phase, moonrise/moonset (USNO + Sunrise-Sunset.org); NWS frost/freeze alerts
- Phase 5a: Frost Risk (derived — radiative cooling model from temp + cloud cover + wind); Photoperiod (derived — day length classification + seasonal trend)
- Phase 5b: Growing Degree Days (season-to-date since Jan 1, base 10°C / 50°F, ERA5 archive + recent forecast bridge); Chill Hours (season-to-date since Nov 1 / May 1, asymmetric linear temperature model ±5%)
- DLI Accumulator — accumulated daily light integral from TSL2591 lux sensor; 30+ crop presets with DLI target ranges; user-defined custom presets; progress shown as percentage of daily target

**Preferences persistence (`/prefs`)**
- Board is source of truth; localStorage is write-through cache and offline fallback
- Persisted: location, active agri params, units, refresh rate, auto-sync, font scales, tooltip toggle, per-source enabled state, card visibility per board, DLI crop preset/target/user presets, GDD base temperature, season start date
- `proxyFetch()` — tries `/proxy` first; falls back to direct browser fetch if board has no internet (desktop use case)
- `externalFetchDone` flag — chips show `—` instead of `Loading…` when all fetches complete with no data

---

## Host Firmware

### v0.8.1 — Hardware
- Added KiCad 9.0 design files for Brain Board V2.0 (schematic, PCB layout, project file)
- Added `hardware/README.md` with key specs, I2C address table, and architecture note
- Fixed TCA9534 I2C address in `Brain_Board_Reference.md` — corrected from 0x20 to 0x27

### v0.8.1 — 2026-03-20
- Added `GET /i2c-scan` endpoint — scans I2C bus (SDA IO6, SCL IO7), returns JSON array of found addresses
- Added tab navigation shell to dashboard webapp — fixed top bar with 5 tabs
- New tabs: Dashboard | I2C Scanner | Devices | Rules | Settings
- Added I2C Scanner tab — manual scan button, address map grid (0x08–0x77), 125+ device database with identification
- Sidebar (Relay + Agri Data) now only visible on Dashboard tab
- Connection status pill moved into tab nav bar
- TSL2591 (0x29) and SHTC3 (0x70) labeled as Automato Onboard
- TCA9534 (0x27) correctly labeled as external Qwiic board — not onboard Brain Board PCB
- DS3231 (0x68) pre-labeled in database as reserved for next Brain Board revision
- Devices, Rules, and Settings tabs present as placeholder shells
- Firmware version bumped to 0.8.1

### v0.8.0 — WiFi Provisioning + mDNS
- **No more hardcoded credentials** — WiFi SSID and password entered via captive portal, stored in NVS
- **AP+STA mode** — Board 1 always runs SoftAP (`Automato-XXXX`) alongside WiFi connection; setup page always reachable at `192.168.4.1`
- **Captive portal** — phones and laptops auto-open setup page when connecting to AP
- **mDNS** — board reachable at `boardname.local` (or `automato-XXXX.local` if no name set)
- **Custom board name** — set during provisioning; used as AP SSID and mDNS hostname; validated (letters, numbers, spaces, hyphens only)
- **Boot button credential reset** — hold IO9 for 5 seconds at startup to clear stored credentials
- **Setup UI** — show/hide password toggle; countdown redirect after save; inline validation warning
- **Captive portal redirect** — `onNotFound` redirects any unknown URL to `/setup`
- **LR protocol fix** — `WIFI_PROTOCOL_LR` moved to STA interface only; AP stays on standard 802.11b/g/n

### v0.7.0 — LittleFS + OTA
- Dashboard HTML moved from PROGMEM to LittleFS — firmware and webapp update independently
- Self-seeding first boot — firmware writes its own LittleFS if not present; no external flash tool needed
- `/update` OTA browser UI served from PROGMEM (always available even if LittleFS fails)
- `/update/firmware` POST endpoint — flashes new `.bin` over the air
- `/update/filesystem` POST endpoint — flashes new LittleFS image over the air
- `/version` endpoint returns current firmware/webapp version string
- Custom partition table: dual OTA slots + LittleFS

### v0.6.1 — TCA9534 Address Fix
- Fixed TCA9534 I2C address from 0x20 to 0x27
- SparkFun Qwiic GPIO board has all address jumpers bridged by default (A0=1, A1=1, A2=1)
- Discovered via I2C scanner diagnostic

### v0.6 — Relay Control
- Added relay control via SparkFun Qwiic GPIO (TCA9534)
- Relay defaults OFF at boot, sensor failure, and connectivity loss — always
- Added `/relay` and `/relay/status` HTTP endpoints
- Added collapsible Relay Control section to dashboard sidebar
- Manual ON/OFF toggle always overrides automation rules
- Rule engine data structures (`Rule`, `Condition`, `evaluateRules`) stubbed for v0.9

### v0.5 — Agri Data Sidebar
- Added Agri Data sidebar with location search (city, zip, lat/lon)
- Metric/Imperial units toggle
- Parameter dropdown grouped by category with source labels
- Active parameters displayed as chips with live values
- External data refreshes every 60 seconds
- All API calls browser-side — board code unchanged
- Sources: Open-Meteo (weather, soil, solar, UV, ET0, VPD), Sunrise-Sunset.org (sun/moon), Open-Meteo AQI (PM2.5, pollen)

### v0.4 — WiFi Fix
- Fixed WiFi connection failure caused by LR protocol being set on STA interface before connecting
- LR now enabled on STA interface only, after WiFi connects

### v0.3 — ESP-NOW Callback Fix
- Fixed ESP-NOW send callback signature for ESP-IDF v5.5+
- wifi_tx_info_t* replaces uint8_t* mac in send callback

### v0.2 — Two-Board Support
- Added ESP-NOW LR two-board support
- Split into Host and Remote sketches
- Shared SensorPayload struct

### v0.1 — Initial Release
- Single-board sensor web dashboard
- SHTC3 temperature/humidity
- TSL2591 ambient light
- Dark theme dashboard with live updates

---

## Remote Firmware

### v0.5 — Channel Scan
- **Automatic channel detection** — scans channels 1-13 at startup, sends ping on each, locks to whichever channel Host ACKs on; no more hardcoded channel
- **Re-scan on timeout** — if no ACK received for 30 seconds, re-scans all channels automatically
- **LR protocol fix** — WIFI_PROTOCOL_LR moved to STA interface only (matches Host v0.8 fix)
- Serial output includes locked channel: Sending > Temp: 24.1C  Hum: 45.0%  Lux: 88.3  ch:6

### v0.4 — WiFi Fix
- Aligned with Host ESP-NOW LR setup order fix

### v0.3 — Callback Fix
- Fixed send callback signature for ESP-IDF v5.5+

### v0.2 — Initial Remote Sketch
- Reads SHTC3 + TSL2591
- Sends SensorPayload to Host MAC every 3 seconds via ESP-NOW LR

---

## Tools

### I2C_Scanner — v1.0
- Generic I2C bus scanner for Brain Board V2.0
- Scans all 127 possible addresses
- Labels known onboard devices (SHTC3, TSL2591) and all 8 possible TCA9534 addresses
- Any unknown device reported with its address
- Brain Board specific: Wire.begin(6, 7) for SDA=IO6, SCL=IO7

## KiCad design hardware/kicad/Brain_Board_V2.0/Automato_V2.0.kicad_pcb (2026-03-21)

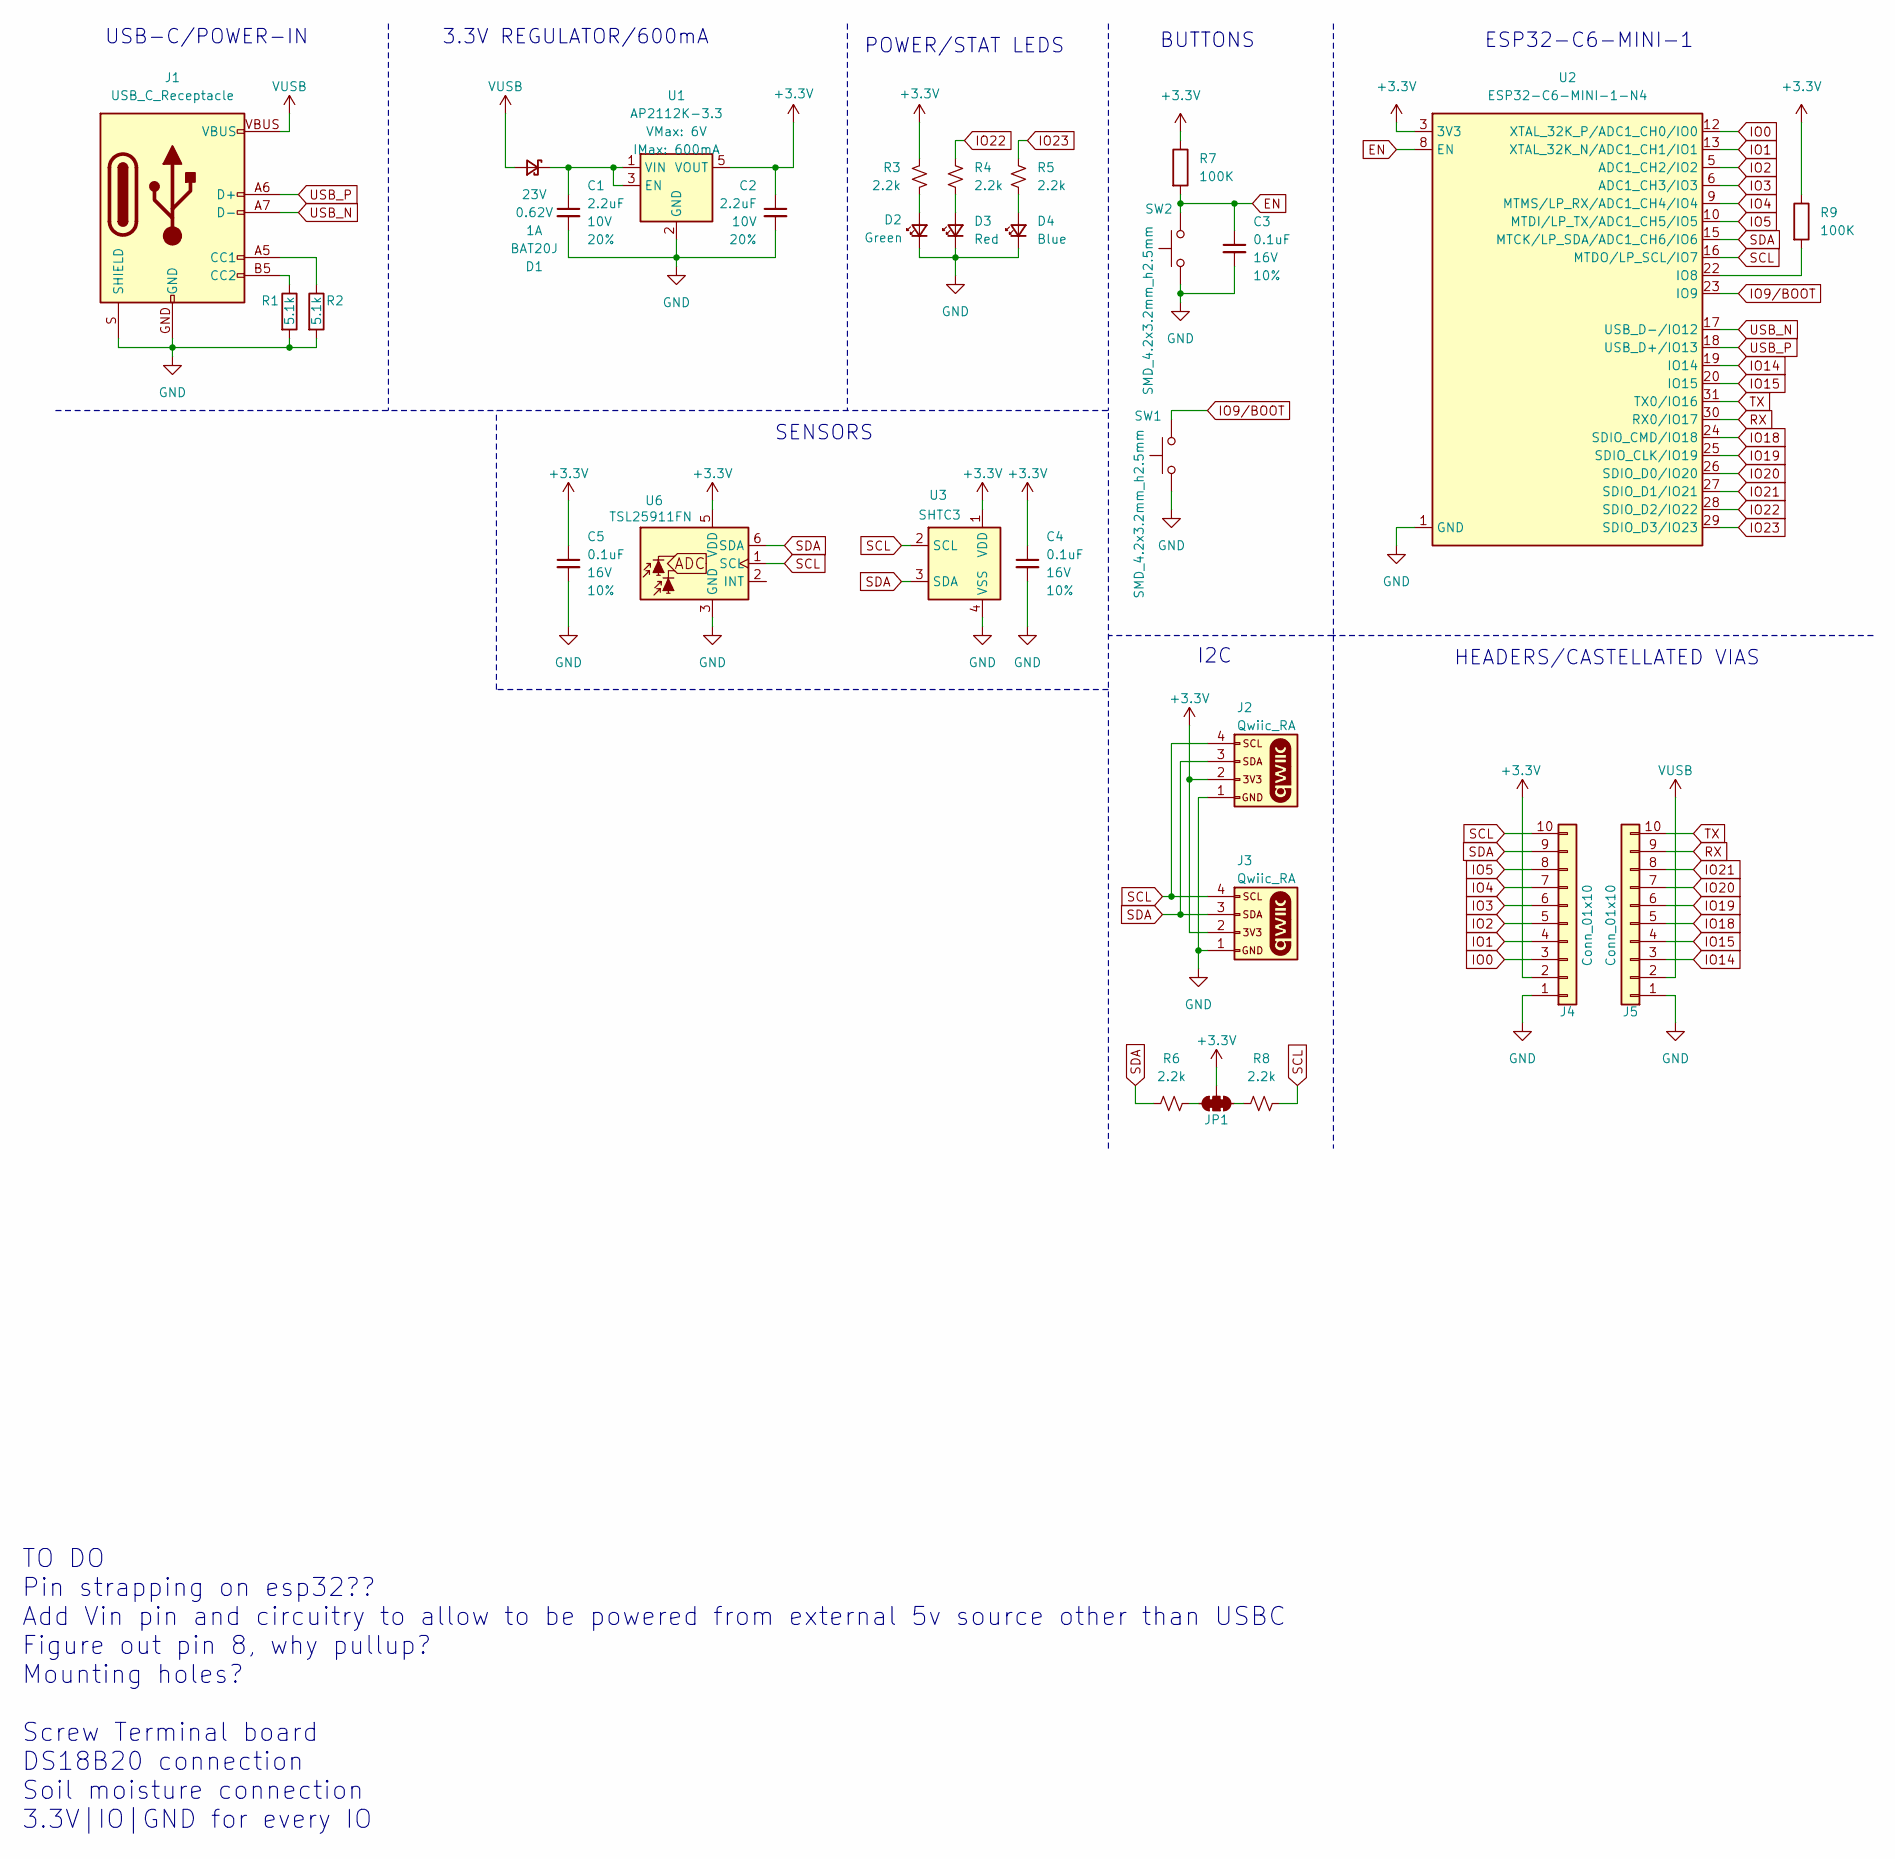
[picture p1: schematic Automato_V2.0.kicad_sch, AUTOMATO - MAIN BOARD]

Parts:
C1, C2: 2.2uF; C_0603_1608Metric; Voltage 10V; Tolerance 20%
C3, C4, C5: 0.1uF; C_0402_1005Metric; Voltage 16V; Tolerance 10%
D1: BAT20J; SOD-323
D2: Green; LED_0603_1608Metric_Green
D3: Red; LED_0603_1608Metric_Red
D4: Blue; LED_0603_1608Metric_Blue
J1: USB_C_Receptacle; USB-C_16
J2, J3: Qwiic_RA; JST_SMD_1.0mm-4_Black
J4, J5: Conn_01x10; 1x10_Castellated
JP1: Jumper_3_NC-2_Trace
R1, R2: 5.1k; R_0402_1005Metric
R3, R4, R5, R6, R8: 2.2k; R_0402_1005Metric
R7, R9: 100K; R_0402_1005Metric
SW1, SW2: SMD_4.2x3.2mm_h2.5mm; Push_SMD_4.2x3.2mm
U1: AP2112K-3.3; SOT23-5
U2: ESP32-C6-MINI-1-N4; ESP32-C6-MINI-1
U3: SHTC3; Sensirion_DFN-4-1EP_2x2mm_P1mm_EP0.7x1.6mm
U6: TSL25911FN; AMS_TSL25911FN

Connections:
+3.3V: C2.1, C4.1, C5.1, J2.2, J3.2, J4.2, JP1.2 (B), R3.2, R7.1, R9.1, U1.5 (VOUT), U2.3 (3V3), U3.1 (VDD), U6.5 (VDD)
EN: C3.1, R7.2, SW2.2, U2.8 (EN)
GND: C1.2, C2.2, C3.2, C4.2, C5.2, D2.1 (K), D3.1 (K), D4.1 (K), J1.GND, J1.S (SHIELD), J2.1, J3.1, J4.1, J5.1, R1.2, R2.2, SW1.1, SW2.1, U1.2 (GND), U2.1 (GND), U2.2 (GND), U2.11 (GND), U2.14 (GND), U2.36 (GND), U2.37 (GND), U2.38 (GND), U2.39 (GND), U2.40 (GND), U2.41 (GND), U2.42 (GND), U2.43 (GND), U2.44 (GND), U2.45 (GND), U2.46 (GND), U2.47 (GND), U2.48 (GND), U2.49 (GND), U2.50 (GND), U2.51 (GND), U2.52 (GND), U2.53 (GND), U3.4 (VSS), U6.3 (GND)
IO0: J4.3, U2.12 (XTAL_32K_P/ADC1_CH0/IO0)
IO1: J4.4, U2.13 (XTAL_32K_N/ADC1_CH1/IO1)
IO2: J4.5, U2.5 (ADC1_CH2/IO2)
IO3: J4.6, U2.6 (ADC1_CH3/IO3)
IO4: J4.7, U2.9 (MTMS/LP_RX/ADC1_CH4/IO4)
IO5: J4.8, U2.10 (MTDI/LP_TX/ADC1_CH5/IO5)
IO9/BOOT: SW1.2, U2.23 (IO9)
IO14: J5.3, U2.19 (IO14)
IO15: J5.4, U2.20 (IO15)
IO18: J5.5, U2.24 (SDIO_CMD/IO18)
IO19: J5.6, U2.25 (SDIO_CLK/IO19)
IO20: J5.7, U2.26 (SDIO_D0/IO20)
IO21: J5.8, U2.27 (SDIO_D1/IO21)
IO22: R4.2, U2.28 (SDIO_D2/IO22)
IO23: R5.2, U2.29 (SDIO_D3/IO23)
unnamed: C1.1, D1.1 (K), U1.1 (VIN), U1.3 (EN)
unnamed: D2.2 (A), R3.1
unnamed: D3.2 (A), R4.1
unnamed: D4.2 (A), R5.1
unnamed: J1.A5 (CC1), R2.1
unnamed: J1.B5 (CC2), R1.1
unnamed: JP1.1 (A), R8.1
unnamed: JP1.3 (C), R6.2
unnamed: R9.2, U2.22 (IO8)
RX: J5.9, U2.30 (RX0/IO17)
SCL: J2.4, J3.4, J4.10, R8.2, U2.16 (MTDO/LP_SCL/IO7), U3.2 (SCL), U6.1 (SCL)
SDA: J2.3, J3.3, J4.9, R6.1, U2.15 (MTCK/LP_SDA/ADC1_CH6/IO6), U3.3 (SDA), U6.6 (SDA)
TX: J5.10, U2.31 (TX0/IO16)
USB_N: J1.A7 (D-), J1.B7 (D-), U2.17 (USB_D-/IO12)
USB_P: J1.A6 (D+), J1.B6 (D+), U2.18 (USB_D+/IO13)
VUSB: D1.2 (A), J1.VBUS, J5.2

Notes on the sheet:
USB-C/POWER-IN
TO DO Pin strapping on esp32?? Add Vin pin and circuitry to allow to be powered from external 5v source other than USBC Figure out pin 8, why pullup? Mounting holes? Screw Terminal board DS18B20 connection Soil moisture connection 3.3V|IO|GND for every IO
ESP32-C6-MINI-1
BUTTONS
SENSORS
POWER/STAT LEDS
I2C
HEADERS/CASTELLATED VIAS
3.3V REGULATOR/600mA

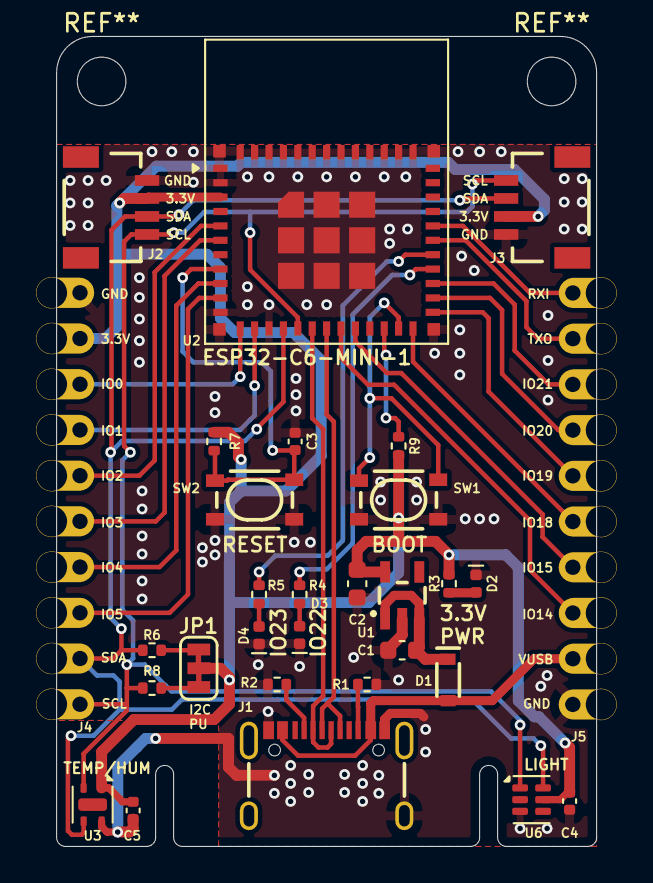
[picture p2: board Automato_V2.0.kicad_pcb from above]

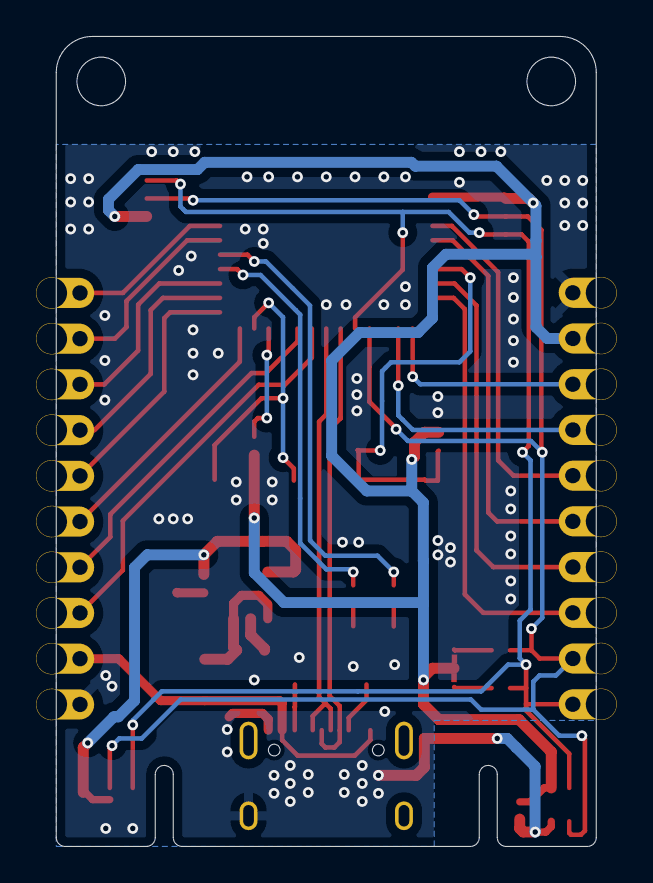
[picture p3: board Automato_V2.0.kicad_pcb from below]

Board: 2 copper layers, 30.0 x 45.0 mm, 30 parts (2 on the bottom side), 34 nets.

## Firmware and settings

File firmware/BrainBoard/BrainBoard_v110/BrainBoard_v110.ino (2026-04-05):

/*
 * BrainBoard_v110.ino
 *
 * Automato Brain Board — Unified Firmware v1.1.0
 *
 * All boards run identical firmware. Roles (gateway / peer) are
 * determined dynamically at runtime — not assigned by the user.
 *
 * Changelog:
 *   v1.1.0 — Unified firmware. All boards are full peers.
 *             MSG_HELLO auto-discovery beacon (burst + settle cadence).
 *             Peer table: boards with matching Network Name auto-register.
 *             Dynamic gateway election: WiFi board with best RSSI wins.
 *             networkname.local mDNS advertised by gateway.
 *             1-hop relay: non-WiFi boards push sensor data to gateway.
 *             GET /peers endpoint: full peer list as JSON.
 *             POST /time endpoint: manual time sync from browser device.
 *             Plugin hooks: customSetup(), customLoop(), customDataJSON().
 *             NTP time sync on WiFi connect; hourly re-sync.
 *
 * Required libraries (Arduino Library Manager):
 *   - Adafruit SHTC3 Library        (search "Adafruit SHTC3")
 *   - Adafruit TSL2591              (search "Adafruit TSL2591")
 *   - Adafruit BusIO                (install when prompted)
 *   - Adafruit Unified Sensor       (install when prompted)
 *   - SparkFun TCA9534 GPIO Expander (search "SparkFun TCA9534")
 *   Built-in: LittleFS, Update, FS, Preferences, ESPmDNS, time.h
 *
 * Arduino IDE settings:
 *   Board:            ESP32C6 Dev Module
 *   Partition Scheme: Custom  (partitions.csv in sketch folder)
 *   USB CDC On Boot:  Enabled  (CRITICAL — resets each session)
 *
 * FIRST FLASH:
 *   1. Flash this sketch (Sketch → Upload).
 *   2. Connect to Automato-XXXX WiFi, open http://192.168.4.1/setup.
 *   3. Enter WiFi credentials and Network Name, click Save & Connect.
 *   4. Upload webapp: http://<board>.local/update → Webapp tab.
 *
 * RESET WIFI CREDENTIALS:
 *   - Hold Boot button (IO9) for 5 seconds at startup, OR
 *   - Use Reset WiFi Credentials button in Settings tab.
 */

#include <WiFi.h>
#include <WebServer.h>
#include <ESPmDNS.h>
#include <DNSServer.h>
#include <Preferences.h>
#include <esp_now.h>
#include <esp_wifi.h>
#include <Wire.h>
#include <FS.h>
#include <LittleFS.h>
#include <Update.h>
#include <time.h>
#include <HTTPClient.h>
#include <WiFiClientSecure.h>
#include "Adafruit_SHTC3.h"
#include <Adafruit_TSL2591.h>
#include <SparkFun_TCA9534.h>

// ─────────────────────────────────────────────
// Hardware pin definitions
// ─────────────────────────────────────────────
#define PIN_SDA    6
#define PIN_SCL    7
#define PIN_LED_B  23
#define PIN_LED_R  22
#define PIN_BOOT   9

// ─────────────────────────────────────────────
// Version
// ─────────────────────────────────────────────
#define FIRMWARE_VERSION  "1.1.0"
#define WEBAPP_VERSION    "1.1.0"

// ─────────────────────────────────────────────
// NVS
// ─────────────────────────────────────────────
Preferences prefs;

// ─────────────────────────────────────────────
// WiFi / provisioning state
// ─────────────────────────────────────────────
char  wifiSSID[64]     = "";
char  wifiPassword[64] = "";
char  boardName[32]    = "";
char  apSSID[32]       = "";
char  mdnsName[32]     = "";
char  networkName[33]  = "";
char  networkPass[33]  = "";
bool  wifiConnected    = false;
bool  hasCredentials   = false;
uint8_t myMac[6]       = {};

// SoftAP management
uint8_t       softApMode      = 0;     // 0=auto (off when WiFi up), 1=always on
bool          softApActive    = true;  // current SoftAP state
unsigned long softApTempUntil = 0;     // millis() when temp window expires; 0=inactive

// Setup page pending reboot (PRG pattern)
bool          pendingReboot   = false;
unsigned long pendingRebootMs = 0;

// Channel seek (non-WiFi boards — find mesh channel non-blocking)
volatile bool channelLocked     = false; // set by recv callback when matching beacon heard
uint8_t       meshChannel       = 1;     // current locked channel
uint8_t       seekChannelIdx    = 0;     // index into seek channel sequence
unsigned long seekLastAdvanceMs = 0;     // last channel advance timestamp
unsigned long seekStartMs       = 0;     // when seek began (for periodic fast-beacon kick)

// ─────────────────────────────────────────────
// Filesystem state
// ─────────────────────────────────────────────
bool lfsOk = false;
char webappVersion[32] = WEBAPP_VERSION;

// ─────────────────────────────────────────────
// ESP-NOW packet types
// All packets begin with a uint8_t type discriminator.
// ─────────────────────────────────────────────
#define MSG_SCAN_REQUEST  0x01
#define MSG_SCAN_RESPONSE 0x02
#define MSG_HELLO         0x03   // discovery beacon
#define MSG_SENSOR        0x04   // sensor data relay (non-gateway → gateway)

// ─────────────────────────────────────────────
// HelloPayload — broadcast by every board periodically.
// Boards with matching networkName auto-register as ESP-NOW peers.
// ─────────────────────────────────────────────
typedef struct {
  uint8_t  type;              // MSG_HELLO
  char     networkName[33];   // must match to join
  char     boardName[33];     // individual board identity
  uint8_t  mac[6];            // sender MAC (redundant with recv_info, but explicit)
  bool     hasWiFi;           // does this board have active WiFi router connection?
  int8_t   rssi;              // WiFi RSSI (-127 if no WiFi) — used for gateway election
  uint32_t unixTime;          // current unix timestamp (0 if unknown)
  bool     timeValid;         // true if unixTime should be trusted
  uint8_t  timeSyncSource;    // 0=none, 1=peer-inherited, 2=manual/browser, 3=NTP/RTC
  uint32_t secondsSinceSync;  // seconds since last authoritative time sync
} HelloPayload;

// ─────────────────────────────────────────────
// SensorBroadcastPayload — sent by non-gateway boards to gateway
// ─────────────────────────────────────────────
typedef struct {
  uint8_t  type;       // MSG_SENSOR
  uint8_t  mac[6];     // sender MAC
  float    tempC;
  float    tempF;
  float    humidity;
  float    lux;
  uint16_t visible;
  uint16_t infrared;
  bool     shtcOk;
  bool     tslOk;
  uint32_t uptime;     // seconds
  float    dieTemp;   // ESP32 internal die temperature (°C)
} SensorBroadcastPayload;

// ─────────────────────────────────────────────
// Remote I2C scan packets (retained from v0.9)
// ─────────────────────────────────────────────
typedef struct { uint8_t type; } ScanRequestPayload;

typedef struct {
  uint8_t type;
  uint8_t count;
  uint8_t addrs[32];
} ScanResponsePayload;

// ─────────────────────────────────────────────
// Peer table
// Tracks all boards that have responded to our Network Name.
// ─────────────────────────────────────────────
#define MAX_PEERS        20    // ESP-NOW hard limit
#define PEER_TIMEOUT_MS  90000 // 3 missed 30-sec beacons → offline

typedef struct {
  uint8_t  mac[6];
  char     boardName[33];
  bool     active;             // false = slot unused or timed out
  bool     hasWiFi;
  int8_t   rssi;
  unsigned long lastSeen;      // millis()

  // Time info received in their beacon
  uint32_t unixTime;
  bool     timeValid;
  uint8_t  timeSyncSource;
  uint32_t secondsSinceSync;

  // Sensor data (from MSG_SENSOR packets)
  float    tempC, tempF, humidity, lux;
  uint16_t visible, infrared;
  bool     shtcOk, tslOk;
  uint32_t sensorUptime;
  float    dieTemp;
  unsigned long sensorLastUpdated; // millis(), 0 if never received

  // I2C scan results
  uint8_t  scanAddrs[32];
  uint8_t  scanCount;
  bool     scanReady;
} PeerInfo;

PeerInfo peers[MAX_PEERS];
uint8_t  peerCount = 0;

// Broadcast MAC — used to send beacons to all boards in range
uint8_t broadcastMac[6] = {0xFF, 0xFF, 0xFF, 0xFF, 0xFF, 0xFF};

// ─────────────────────────────────────────────
// Gateway state
// ─────────────────────────────────────────────
bool    isGateway     = false;
bool    wasGateway    = false;  // to detect transitions
uint8_t gatewayMac[6] = {};
bool    gatewayKnown  = false;

// ─────────────────────────────────────────────
// Beacon timing — burst + settle
// ─────────────────────────────────────────────
#define BEACON_FAST_MS      5000   // 5 sec during fast phase
#define BEACON_SLOW_MS      30000  // 30 sec in steady state
#define BEACON_FAST_DURATION_MS 60000  // fast phase duration on trigger

unsigned long beaconLastSent    = 0;
unsigned long beaconFastStartMs = 0;
bool          beaconFastMode    = true;  // start in fast mode

// ─────────────────────────────────────────────
// Sensor broadcast timing (non-gateway → gateway)
// ─────────────────────────────────────────────
#define SENSOR_BROADCAST_MS  30000  // every 30 sec

unsigned long sensorLastBroadcast = 0;

// ─────────────────────────────────────────────
// Time state
// ─────────────────────────────────────────────
bool          timeValid       = false;
uint8_t       timeSyncSource  = 0;    // 0=none, 1=peer, 2=manual/browser, 3=NTP
unsigned long lastSyncMillis  = 0;

#define NTP_RESYNC_MS  3600000  // re-sync NTP hourly
unsigned long lastNtpSync = 0;

// ─────────────────────────────────────────────
// Hardware objects
// ─────────────────────────────────────────────
Adafruit_SHTC3   shtc3;
Adafruit_TSL2591 tsl(2591);
TCA9534          gpio0;
WebServer        server(80);
DNSServer        dnsServer;

// ─────────────────────────────────────────────
// Local sensor state
// ─────────────────────────────────────────────
float    b1_tempC    = 0.0;
float    b1_tempF    = 0.0;
float    b1_humidity = 0.0;
float    b1_lux      = 0.0;
uint16_t b1_visible  = 0;
uint16_t b1_infrared = 0;
bool     b1_shtcOk   = false;
bool     b1_tslOk    = false;
float    b1_dieTemp  = 0.0;

// ─────────────────────────────────────────────
// Relay state
// ─────────────────────────────────────────────
bool gpioOk         = false;
bool relayState     = false;
bool manualOverride = true;
#define NUM_RELAYS 1

void applyRelay() {
  if (!gpioOk) return;
  gpio0.digitalWrite(0, relayState ? HIGH : LOW);
}

void forceAllRelaysOff() {
  relayState = false;
  if (gpioOk) gpio0.digitalWrite(0, LOW);
}

// ─────────────────────────────────────────────
// Rule engine — stubs (v1.2)
// ─────────────────────────────────────────────
#define MAX_CONDITIONS 16
#define MAX_RULES      16

struct Condition {
  char    source[48];  // e.g. "local.tempC" or "peer:AA:BB:CC:DD:EE:FF.tempC"
  uint8_t condOp;      // 0=above, 1=below, 2=equals
  float   threshold;
};

struct Rule {
  char      name[32];
  uint8_t   priority;
  uint8_t   op;                        // 0=AND, 1=OR, 2=NOT, 3=XOR
  bool      relayTargets[NUM_RELAYS];
  bool      relayAction;
  Condition conditions[MAX_CONDITIONS];
  uint8_t   conditionCount;
  bool      enabled;
};

Rule    rules[MAX_RULES];
uint8_t ruleCount = 0;

bool evalCondition(uint8_t ri, uint8_t ci) {
  const Condition& c = rules[ri].conditions[ci];
  float val = 0.0;
  bool  found = false;
  if      (strcmp(c.source, "local.tempC")    == 0) { val = b1_tempC;    found = true; }
  else if (strcmp(c.source, "local.tempF")    == 0) { val = b1_tempF;    found = true; }
  else if (strcmp(c.source, "local.humidity") == 0) { val = b1_humidity; found = true; }
  else if (strcmp(c.source, "local.lux")      == 0) { val = b1_lux;      found = true; }
  if (!found) return false;
  switch (c.condOp) {
    case 0: return val >  c.threshold;
    case 1: return val <  c.threshold;
    case 2: return fabsf(val - c.threshold) < 0.01f;
    default: return false;
  }
}

bool evalRule(uint8_t ri) {
  const Rule& r = rules[ri];
  if (!r.enabled || r.conditionCount == 0) return false;
  uint8_t trueCount = 0;
  for (uint8_t ci = 0; ci < r.conditionCount; ci++)
    if (evalCondition(ri, ci)) trueCount++;
  switch (r.op) {
    case 0: return trueCount == r.conditionCount;
    case 1: return trueCount > 0;
    case 2: return trueCount == 0;
    case 3: return trueCount == 1;
    default: return false;
  }
}

void evaluateRules() {
  if (manualOverride) return;
  for (uint8_t ri = 0; ri < NUM_RELAYS; ri++) {
    bool    found        = false;
    bool    winnerAction = false;
    uint8_t winnerPrio   = 255;
    for (uint8_t i = 0; i < ruleCount; i++) {
      if (!rules[i].enabled)          continue;
      if (!rules[i].relayTargets[ri]) continue;
      if (!evalRule(i))               continue;
      if (rules[i].priority < winnerPrio) {
        winnerPrio   = rules[i].priority;
        winnerAction = rules[i].relayAction;
        found        = true;
      }
    }
    if (ri == 0) relayState = found ? winnerAction : false;
  }
  applyRelay();
}

// ─────────────────────────────────────────────
// Plugin hooks — weak functions
// User implements these in a separate custom.ino file.
// Arduino concatenates all .ino files at compile time.
// ─────────────────────────────────────────────
void   __attribute__((weak)) customSetup()             {}
void   __attribute__((weak)) customLoop()              {}
String __attribute__((weak)) customDataJSON()          { return "{}"; }

// ─────────────────────────────────────────────
// Utility: MAC to string
// ─────────────────────────────────────────────
void macToStr(const uint8_t* mac, char* buf, size_t len) {
  snprintf(buf, len, "%02X:%02X:%02X:%02X:%02X:%02X",
           mac[0], mac[1], mac[2], mac[3], mac[4], mac[5]);
}

bool macEquals(const uint8_t* a, const uint8_t* b) {
  return memcmp(a, b, 6) == 0;
}

// ─────────────────────────────────────────────
// Time functions
// ─────────────────────────────────────────────
uint32_t getUnixTime() {
  if (!timeValid) return 0;
  time_t now;
  time(&now);
  return (uint32_t)now;
}

uint32_t getSecondsSinceSync() {
  if (!timeValid || timeSyncSource == 0) return UINT32_MAX;
  return (uint32_t)((millis() - lastSyncMillis) / 1000UL);
}

void applyUnixTime(uint32_t unixTime, uint8_t source, uint32_t peerSecondsSinceSync) {
  time_t t = (time_t)unixTime;
  struct timeval tv = { .tv_sec = t };
  settimeofday(&tv, NULL);
  timeValid      = true;
  timeSyncSource = source;
  // Back-calculate when the source was actually synced
  lastSyncMillis = millis() - (peerSecondsSinceSync * 1000UL);
  Serial.printf("Time applied: unix=%u  source=%u  peerAge=%us\n",
                unixTime, source, peerSecondsSinceSync);
}

void ntpSync() {
  if (!wifiConnected) return;
  configTime(0, 0, "pool.ntp.org", "time.nist.gov");
  // Wait up to 3 seconds for NTP response
  struct tm timeinfo;
  unsigned long start = millis();
  while (!getLocalTime(&timeinfo, 100) && millis() - start < 3000) {}
  if (getLocalTime(&timeinfo, 0)) {
    timeValid      = true;
    timeSyncSource = 3;  // NTP
    lastSyncMillis = millis();
    lastNtpSync    = millis();
    Serial.printf("NTP sync OK: %04d-%02d-%02d %02d:%02d:%02d UTC\n",
                  timeinfo.tm_year + 1900, timeinfo.tm_mon + 1, timeinfo.tm_mday,
                  timeinfo.tm_hour, timeinfo.tm_min, timeinfo.tm_sec);
  } else {
    Serial.println("NTP sync failed (no response).");
  }
}

void maybeSyncTimeFromPeer(uint32_t peerUnixTime, bool peerTimeValid,
                           uint8_t peerSyncSource, uint32_t peerSecondsSinceSync) {
  if (!peerTimeValid || peerUnixTime == 0) return;
  bool shouldSync =
    !timeValid ||
    (peerSyncSource > timeSyncSource) ||
    (peerSyncSource == timeSyncSource && peerSecondsSinceSync < getSecondsSinceSync());
  if (!shouldSync) return;
  // We are one hop away from the source — cap our source at "peer-inherited"
  uint8_t adoptedSource = (peerSyncSource >= 3) ? 3 : peerSyncSource;
  applyUnixTime(peerUnixTime, adoptedSource, peerSecondsSinceSync);
}

// ─────────────────────────────────────────────
// Peer management
// ─────────────────────────────────────────────

// Returns index of peer matching mac, or -1 if not found.
int findPeer(const uint8_t* mac) {
  for (int i = 0; i < MAX_PEERS; i++) {
    if (peers[i].active && macEquals(peers[i].mac, mac)) return i;
  }
  return -1;
}

// Returns index of first unused slot, or -1 if full.
int freePeerSlot() {
  for (int i = 0; i < MAX_PEERS; i++)
    if (!peers[i].active) return i;
  return -1;
}

// Recounts active peers.
void recountPeers() {
  peerCount = 0;
  for (int i = 0; i < MAX_PEERS; i++)
    if (peers[i].active) peerCount++;
}

// Register mac as an ESP-NOW unicast peer if not already registered.
void ensureEspNowPeer(const uint8_t* mac) {
  if (esp_now_is_peer_exist(mac)) return;
  esp_now_peer_info_t peer = {};
  memcpy(peer.peer_addr, mac, 6);
  peer.channel = 0;
  peer.encrypt = false;
  esp_err_t err = esp_now_add_peer(&peer);
  if (err == ESP_OK) {
    char ms[18]; macToStr(mac, ms, sizeof(ms));
    Serial.printf("ESP-NOW peer registered: %s\n", ms);
  }
}
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
void loop() {
  dnsServer.processNextRequest();
  server.handleClient();
  customLoop();

  unsigned long now = millis();

  // ── Beacon timer (burst + settle) ───────────
  {
    bool inFast = beaconFastMode &&
                  (now - beaconFastStartMs < BEACON_FAST_DURATION_MS);
    if (!inFast && beaconFastMode) {
      beaconFastMode = false;
      Serial.println("Beacon: fast phase complete, switching to 30s steady state.");
    }
    unsigned long interval = inFast ? BEACON_FAST_MS : BEACON_SLOW_MS;
    if (now - beaconLastSent >= interval) {
      sendBeacon();
      beaconLastSent = now;
    }
  }

  // ── Peer timeout check (every 10s) ──────────
  {
    static unsigned long lastTimeoutCheck = 0;
    if (now - lastTimeoutCheck >= 10000) {
      lastTimeoutCheck = now;
      uint8_t prevCount = peerCount;
      timeoutPeers();
      electGateway();
      if (prevCount > 0 && peerCount == 0) {
        // All peers lost — re-enter fast beacon so others can find us quickly
        beaconFastMode    = true;
        beaconFastStartMs = now;
        Serial.println("All peers lost — fast beacon restarted.");
      }
      if (!wifiConnected && prevCount > 0 && peerCount == 0) {
        // Non-WiFi board lost all peers — resume channel seek
        startChannelSeek();
      }
    }
  }

  // ── Non-blocking channel seek (non-WiFi boards seeking mesh) ──
  if (!wifiConnected && !channelLocked) {
    const uint8_t seekChannels[] = {1, 6, 11, 2, 3, 4, 5, 7, 8, 9, 10};
    if (softApTempUntil > 0 || WiFi.softAPgetStationNum() > 0) {
      // Pause seek: temp window active OR a client is connected to the SoftAP
      seekLastAdvanceMs = now;
    } else if (now - seekLastAdvanceMs >= 3000) {
      // Advance to next channel — restart AP on new channel to move the radio
      seekChannelIdx = (seekChannelIdx + 1) % sizeof(seekChannels);
      setSeekChannel(seekChannels[seekChannelIdx]);
      seekLastAdvanceMs = now;
      Serial.printf("Channel seek: ch %u\n", meshChannel);
    }
    // Every 5 min without locking: re-trigger fast beacon
    if (now - seekStartMs >= 300000UL) {
      beaconFastMode    = true;
      beaconFastStartMs = now;
      seekStartMs       = now;
      Serial.println("Channel seek: 5-min kick — fast beacon restarted.");
    }
  }

  // ── Sensor broadcast to gateway (non-gateway boards) ───
  {
    if (!isGateway && gatewayKnown &&
        now - sensorLastBroadcast >= SENSOR_BROADCAST_MS) {
      readLocalSensors();
      sendSensorToGateway();
      sensorLastBroadcast = now;
    }
  }

  // ── NTP hourly re-sync ───────────────────────
  if (wifiConnected && now - lastNtpSync >= NTP_RESYNC_MS) {
    ntpSync();
  }

  // ── Rule engine ─────────────────────────────
  // evaluateRules();  // enabled in v1.2

  // ── Heartbeat LED ────────────────────────────
  {
    static unsigned long lastBlink = 0;
    if (now - lastBlink > 5000 && wifiConnected) {
      lastBlink = now;
      digitalWrite(PIN_LED_B, LOW); delay(60); digitalWrite(PIN_LED_B, HIGH);
    }
  }

  // ── Boot button short press → temp SoftAP ────
  {
    static bool          btnWasDown = false;
    static unsigned long btnDownMs  = 0;
    bool btnDown = (digitalRead(PIN_BOOT) == LOW);
    if (btnDown && !btnWasDown) {
      btnDownMs  = now;
      btnWasDown = true;
    } else if (!btnDown && btnWasDown) {
      unsigned long held = now - btnDownMs;
      if (held >= 50 && held < 5000) {
        softApTempUntil = now + 600000UL;  // 10 minutes
        enableSoftAP();
        Serial.println("SoftAP: 10-min field access window started.");
      }
      btnWasDown = false;
    }
  }

  // ── SoftAP temp window expiry ─────────────────
  if (softApTempUntil > 0 && now >= softApTempUntil) {
    softApTempUntil = 0;
    if (softApMode == 0 && wifiConnected) disableSoftAP();
  }

  // ── Pending reboot (PRG after /setup POST) ────
  if (pendingReboot && millis() - pendingRebootMs >= 3000) {
    ESP.restart();
  }
}

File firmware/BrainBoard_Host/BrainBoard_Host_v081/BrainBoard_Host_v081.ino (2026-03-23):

/*
 * BrainBoard_Host_v08.ino
 *
 * Automato Brain Board V2.0 — Host Node (Board 1)
 *
 * Changelog:
 *   v0.1 — Initial single-board sensor web dashboard
 *   v0.2 — Added two-board ESP-NOW LR support; split into Host + Remote
 *   v0.3 — Fixed ESP-NOW send callback signature for ESP-IDF v5.5+
 *           (wifi_tx_info_t* replaces uint8_t* mac in send cb)
 *   v0.4 — Fixed WiFi connection failure caused by LR mode being set on
 *           STA interface before connecting. Now connects first, then
 *           enables LR on AP interface only for ESP-NOW.
 *   v0.5 — Added Agri Data sidebar: location search, metric/imperial
 *           toggle, Open-Meteo and Sunrise-Sunset.org parameters.
 *   v0.6.1 — Fixed TCA9534 I2C address 0x20 → 0x27. Relay defaults OFF.
 *             Added /relay and /relay/status endpoints. Rule engine stubbed.
 *   v0.7 — Dashboard HTML moved from PROGMEM to LittleFS.
 *           Firmware and webapp now update independently via OTA.
 *           Self-seeding: on first boot, firmware formats LittleFS and
 *           writes webapp files from PROGMEM. No external flash tool needed.
 *           Added /update OTA browser UI (served from PROGMEM, always available).
 *           Added /update/firmware and /update/filesystem OTA endpoints.
 *           Added /version endpoint returning firmware + webapp versions.
 *           Requires custom partitions.csv (included in sketch folder).
 *           Arduino IDE: Tools → USB CDC On Boot → Enabled (required for serial).
 *   v0.8 — WiFi provisioning via NVS (no hardcoded credentials).
 *           AP+STA simultaneous mode — board always reachable at 192.168.4.1.
 *           Captive portal + provisioning form at http://192.168.4.1/setup.
 *           SoftAP name auto-generated from MAC: Automato-XXXX.
 *           User-configurable board name stored in NVS.
 *           mDNS: automato-XXXX.local (or user-defined name).
 *           Boot button (IO9) held 5s at startup → clears credentials.
 *           Dashboard Reset WiFi button → clears credentials + reboots.
 *           Dashboard shows friendly connectivity status (not AP/STA jargon).
 *           /setup endpoint for provisioning form (GET + POST).
 *           /wifi/reset endpoint for dashboard reset button.
 *
 *   v0.8.1 — Added GET /i2c-scan endpoint.
 *           Scans I2C bus (SDA IO6, SCL IO7) for connected devices.
 *           Returns JSON: {"devices":[addr,...]} with decimal addresses.
 *           Tab navigation shell + I2C Scanner tab added to webapp.
 *
 * Required libraries (Arduino Library Manager):
 *   - Adafruit SHTC3 Library        (search "Adafruit SHTC3")
 *   - Adafruit TSL2591              (search "Adafruit TSL2591")
 *   - Adafruit BusIO                (install when prompted)
 *   - Adafruit Unified Sensor       (install when prompted)
 *   - SparkFun TCA9534 GPIO Expander (search "SparkFun TCA9534")
 *   Built-in (no install): LittleFS, Update, FS, Preferences, ESPmDNS
 *
 * Arduino IDE settings:
 *   Board:              ESP32C6 Dev Module
 *   Partition Scheme:   Custom  (uses partitions.csv in sketch folder)
 *   USB CDC On Boot:    Enabled
 *   All other settings: defaults
 *
 * HARDWARE:
 *   Relay board:   Amazon B0CHFJSNP6 (5V coil, optoisolated, active HIGH)
 *   GPIO expander: SparkFun Qwiic GPIO (TCA9534) at I2C address 0x27
 *   Signal path:   TCA9534 pin 0 → Relay board IN
 *   Boot button:   IO9 — hold 5s at startup to clear WiFi credentials
 *
 * RELAY BEHAVIOR:
 *   - Defaults OFF at boot, before any init completes
 *   - Defaults OFF if TCA9534 init fails
 *   - Defaults OFF if sensor read fails
 *   - Manual toggle from dashboard always overrides automation rules
 *   - Manual override persists until user manually changes it again
 *
 * FIRST FLASH:
 *   1. Copy partitions.csv into the sketch folder alongside this .ino file.
 *   2. Set Partition Scheme to Custom and USB CDC On Boot to Enabled.
 *   3. Flash this sketch. On first boot LittleFS will be formatted and
 *      seeded automatically — no separate filesystem upload needed.
 *   4. Open Serial Monitor (115200 baud) + press RESET.
 *   5. Connect phone/laptop to the Automato-XXXX WiFi network.
 *   6. Open http://192.168.4.1/setup to enter WiFi credentials.
 *   7. Board joins your network. Access at http://automato-XXXX.local
 *      or the IP shown in Serial Monitor.
 *   8. Paste Board 1 MAC into BrainBoard_Remote_v04.ino and flash Board 2.
 *
 * RESET WIFI CREDENTIALS:
 *   - Hold Boot button (IO9) for 5 seconds at startup, OR
 *   - Use the Reset WiFi button in the dashboard settings
 *
 * OTA UPDATES (after first flash):
 *   - Firmware:  http://<ip>/update → upload new .bin
 *   - Webapp:    http://<ip>/update → upload new LittleFS .bin
 */

#include <WiFi.h>
#include <WebServer.h>
#include <ESPmDNS.h>
#include <DNSServer.h>
#include <Preferences.h>
#include <esp_now.h>
#include <esp_wifi.h>
#include <Wire.h>
#include <FS.h>
#include <LittleFS.h>
#include <Update.h>
#include "Adafruit_SHTC3.h"
#include <Adafruit_TSL2591.h>
#include <SparkFun_TCA9534.h>   // SparkFun TCA9534 GPIO Expander

// ─────────────────────────────────────────────
// Hardware pin definitions
// ─────────────────────────────────────────────
#define PIN_SDA    6    // I2C data  — Brain Board V2.0
#define PIN_SCL    7    // I2C clock — Brain Board V2.0
#define PIN_LED_B  23   // Blue LED (WiFi connected)
#define PIN_LED_R  22   // Red LED (error)
#define PIN_BOOT   9    // Boot button — hold 5s at startup to clear WiFi credentials

// ─────────────────────────────────────────────
// Version
// ─────────────────────────────────────────────
#define FIRMWARE_VERSION  "0.8.1"
#define WEBAPP_VERSION    "0.8.1"

// ─────────────────────────────────────────────
// NVS namespace
// ─────────────────────────────────────────────
Preferences prefs;

// ─────────────────────────────────────────────
// WiFi / provisioning state
// ─────────────────────────────────────────────
char     wifiSSID[64]     = "";
char     wifiPassword[64] = "";
char     boardName[32]    = "";   // user-defined name (drives AP SSID + mDNS)
char     apSSID[32]       = "";   // Automato-XXXX or custom name
char     mdnsName[32]     = "";   // automato-XXXX or custom name
char     networkName[33]  = "";   // Automato Network Name (mesh + cloud identity)
char     networkPass[33]  = "";   // Automato Network password
bool     wifiConnected    = false;
bool     hasCredentials   = false;

// ─────────────────────────────────────────────
// Filesystem state
// ─────────────────────────────────────────────
bool lfsOk = false;
char webappVersion[32] = WEBAPP_VERSION;  // read from LittleFS at boot
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

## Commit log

2026-03-12 Initial commit — Host v0.6, Remote v0.4
2026-03-12 Create ESP32C6_Capabilities.md
    Add ESP32-C6 unexplored capabilities notes
2026-03-12 Update README.md
    Add ESP32-C6 capabilities link to roadmap
2026-03-17 Sync: Roadmap, v0.6.1 address fix, I2C scanner, ESP32-C6 capabilities update
    [BrainBoard_Host_v0.6.1.ino]
2026-03-17 Add ProductFamily.md and I2C_Address_Map.md — product architecture, connector standard, BOM analysis
2026-03-19 firmware: add BrainBoard_Host_v07 and BrainBoard_Remote_v04
    [partitions.csv]
2026-03-19 v0.8.0 — WiFi provisioning, mDNS, channel scan
    [partitions.csv]
2026-03-20 v0.8.1 — I2C Scanner tab, tab nav shell, /i2c-scan endpoint
    [partitions.csv]
2026-03-21 Add KiCad hardware files for Brain Board V2.0
    [Automato_V2.0.kicad_pcb, Automato_V2.0.kicad_sch]
2026-03-21 v0.8.1 — MCU Temp card, collapsible cards, hover tooltips
2026-03-21 Update roadmap and fix TCA9534 address comment
    - docs/Roadmap.md: major update reflecting decisions from Mar 21 session
    — v0.9 scope corrected to Devices tab + Network Name (not rule engine)
    — Platform phases reversed: Phase 1 = cloud relay, Phase 2 = cloud compile
    — No user accounts model documented throughout
    — Added UX architecture layers, cloud identity, plugin hook architecture
    — Added unrecognized device usability levels
    — Added MicroSD slot decision (IO18-IO21, next PCB revision)
    — Relay Safety Contract updated for failsafe jumper (Normally ON now possible)
    — EX-01 clarified as optional, not required
    — Known decisions table expanded with all new dec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
    [BrainBoard_Host_v081.ino]
2026-03-22 Fix soil temp stuck on Loading in Agri Data sidebar
    Two bugs:
    1. Wrong Open-Meteo variable names — soil_temperature_0_to_7cm and
    soil_temperature_7_to_28cm are not valid current API variables; they
    return null. Corrected to soil_temperature_0cm and soil_temperature_6cm.
    soil_moisture_0_to_7cm corrected to soil_moisture_0_to_1cm.
    2. fmt1(null) crash — isFinite(null) is true in JavaScript (null coerces
    to 0), causing null.toFixed(1) to throw a TypeError. This silently
    crashed the entire fetchWeather() call, leaving all weather params at
    Loading... Added null guard: (n != null && isFinite(n)).
2026-03-22 Add USNO moon data and NOAA NWS frost alerts to Agri Data sidebar
    Moon data (USNO Astronomical Applications API):
    - fetchMoon() calls aa.usno.navy.mil/api/rstt/oneday with current date,
    coords, and browser timezone offset
    - Returns moonrise, moonset, official phase name from authoritative source
    - Falls back to local calcMoonAgeDays() for phase if CORS fails; rise/set
    fall back to — (CORS confirmed working in browser)
    - Moonset shows — on days when moon sets after midnight (correct behavior)
    - Updated dropdown source labels from Sunrise-Sunset.org to USNO
    - Moon fetch decoupled from fetchSolar(); triggered by needsMoon condition
    Frost / Freeze Alert (NOAA NWS):
    - fetchFrost() calls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
2026-03-22 v0.9: Devices tab replacing I2C Scanner, with remote board scanning
    - Replace I2C Scanner tab with Devices tab (4 tabs total)
    - Host board: device cards (onboard/identified/unknown) + collapsible address map
    - Remote board: live I2C scan via ESP-NOW request/response
    - Unknown devices: inline define form, saved to localStorage
    - Host firmware: ScanRequestPayload/ScanResponsePayload structs, capture
    Remote MAC on first packet, register as ESP-NOW peer, GET/POST /remote-scan
    - Remote firmware: onCommandReceived callback, runs Wire scan on request,
    sends ScanResponsePayload back to Host
    - Roadmap: remote I2C scan moved to v0.9 (was v1.0); I2C Scanner tab removed
    from tab count
    Co-Authored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
    [BrainBoard_Host_v081.ino, BrainBoard_Remote_v05.ino]
2026-03-22 v0.9: Automato Network Name, WiFi reset UX, Network Name in Dashboard
    - /setup form: added Network Name + Network Password fields; auto-fills
    from /version JSON; saves to NVS (netname, netpass keys)
    - Auto-generates default network name (automato-XXXX) from MAC suffix
    if no name is saved in NVS
    - /version JSON: added networkName field (34 chars, lowercase)
    - WiFi reset flow: fetches apSSID before reset, shows step-by-step
    reconnection instructions with hardcoded http://192.168.4.1/setup link
    - Setup banner href changed from relative /setup to http://192.168.4.1/setup
    so it remains reachable after board reboots into AP mode
    - Dashboard WiFi status area: displays Network Name below MDN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
    [BrainBoard_Host_v081.ino]
2026-03-22 Update roadmap: custom ESP-NOW mesh architecture, board mobility, v1.0-v1.2 scope
    - Replace ESP-Mesh-Lite with custom ESP-NOW mesh (no external dependencies)
    - Document board mobility as first-class design constraint
    - v1.1: MSG_HELLO beacon, dynamic gateway, networkname.local, 1-hop relay
    - v1.2: multi-hop relay, TTL + duplicate-drop, routing tables, unified firmware
    - v0.9 marked complete; version table updated
    - 5-tab structure documented (Network tab added as stub in v1.0)
    - v1.0 rules confirmed: local board sensors only
    - v1.0 Settings tab: board name, Network Name, WiFi reset
    - Role indicator planned: Gateway / Relay / Isolated (v1.1+)
    - Add session summary: Automato_Session_Mar22_2026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
2026-03-23 v1.0: Settings tab (functional) + Network tab (stub)
    Firmware:
    - Add POST /settings endpoint — saves board name, Network Name, and
    password to NVS without requiring WiFi credentials (POST /setup
    requires ssid field; /settings does not)
    Webapp:
    - Settings tab: pre-fills board name and network name from /version;
    Save POSTs to /settings; WiFi section shows connection status and
    Reset WiFi Credentials button
    - Network tab: HOST/REMOTE role badge, board name, mDNS address,
    Network Name, WiFi status; Coming in v1.1 note explains auto-discovery
    - switchTab() triggers initSettingsTab() and initNetworkTab() on first open
    - Rules tab placeholder updated to reference v1.0 (was v0.9)
    [BrainBoard_Host_v081.ino]
2026-03-28 v1.1: ESP-NOW mesh — unified firmware, channel seek, 1-hop relay, live Network tab
    - Unified firmware: BrainBoard_Host/Remote merged into single BrainBoard build; all boards are full peers
    - MSG_HELLO beacon: auto-discovery by Network Name; boards register ESP-NOW peers without manual config
    - Dynamic gateway election: WiFi-connected board self-elects gateway; non-WiFi boards enter relay role
    - networkname.local mDNS: gateway advertises mDNS hostname derived from Network Name
    - Non-blocking channel seek: non-WiFi boards cycle channels 1–11 (US cc=01) by restarting SoftAP on each channel to keep radio active for ESP-NOW RX; locks on first HELLO match
    - 5-min seek kick: re-triggers fast be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
    [partitions.csv]
2026-03-28 README: full rewrite for v1.1 — unified firmware, mesh, current endpoints and roadmap
2026-03-28 webapp: Settings tab redesign, PRG fix for /setup, board name labels, channel seek fix
    - Settings tab: Display & Behavior section (units, refresh rate, auto-sync time),
    Agri Data Sources submenu (source-level list + per-source parameter drill-down),
    Board Settings master-detail layout (scrollable board list + inline detail panel)
    - Peer board panel: READ ONLY badge, Boot button instruction in SoftAP access note
    - Units toggle moved from Dashboard sidebar to Settings only
    - Dashboard board columns now show actual board names from /version and /peers
    - Show/hide password toggle on /setup form
    - PRG pattern for /setup POST: 303 redirect + countdown page, non-blocking reboot
    - Channel seek t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
    [BrainBoard_v110.ino]
2026-04-05 v1.1: ESP-NOW mesh, agri sidebar phases 1-5b, /proxy, /prefs, Settings redesign
    - Unified firmware (BrainBoard_Host + BrainBoard_Remote merged)
    - MSG_HELLO beacon: auto-discovery, no manual MAC entry
    - Dynamic gateway election: WiFi board with strongest RSSI wins
    - networkname.local mDNS: gateway advertises network name
    - 1-hop relay: channel seek, lock on beacon, sensor forwarding
    - NTP time sync + POST /time endpoint
    - Plugin hook architecture: customSetup/Loop/DataJSON weak functions
    - /proxy endpoint: board-side HTTPS relay, 7-domain allowlist
    - /prefs GET/POST: LittleFS storage + NVS backup (survives uploads)
    - SoftAP captive portal: redirects to dashboard when provisioned
    - /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
    [BrainBoard_v110.ino]
